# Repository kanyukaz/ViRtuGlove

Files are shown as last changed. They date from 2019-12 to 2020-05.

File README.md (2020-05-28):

# ViRtuGlove 0.9
This goal of this project to create a haptic feedback glove that can be used with consumer virtual reality (VR) systems. Presently, the project employs the following core features:
* 3 D0F rotational acceleration tracking for each digit (and for the hand to serve as a reference)
* anti-contractile haptic feedback for each digit
* assessment of contractile resistance against the haptic feedback system

Currently, the project does not have full integration with a VR system, but does include functioning (albeit in need of minor debugging) systems for exchanging sensor and actuator signals with a host computer. Please see the /src folder for my Arduino sketch and a companion script for Unity3D. These scripts provide a foundation for integration with a variety of VR interfaces.



[pic1]: https://github.com/kanyukaz/ViRtuGlove/blob/master/img/prototype.jpg "VR Glove"

Repository Contents
============

* **/documentation** - documentation for this project and its predecessor
* **/hardware** - models for the unused part prototypes and circuit schematics to summarize the electronic boards that I have built
* **/img** - images for the readme, including a product photo and circuit schematic diagrams.
* **/libraries** - the libraries for presently used versions of Adafruit sensor libraries (keeps the code functional in case current versions are not available in the future, and future versions are not backwards compatible).
* **/scr** - the Arduino sketch, the companion script for Unity3D, and code used for debugging

* **LICENSE** - The license file.
* **README.md** - The file you're reading now! :-D

Requirements and Materials
============
Dependencies:
* Adafruit Unified Sensor library V1.0.3
* Adafruit L3GD20 U Sensor library V1.01

Both of these are available through Arduino IDE's built-in library manager, but backups are included in the /libraries section

Bill of Materials:
* 1 x Arduino MEGA
* 1 x VR-capable computer
* 5 x Adafruit L3GD20H gyroscope breakouts
* 1 x Adafruit 9D0F sensor breakouts
* 5 x TOWERPRO SG-5010 servomotors
* 5 x Adafruit INA169 current sensor breakouts
* 1 x TCA9548A I2C multiplexer
* 1 x 180 cm derailleur cable
* 1 x tight-fitting elastic glove 
* L x Velcro
* L x cushion foam
* L x hot glue 
* L x flexible perfboard
* L x ribbon cable
* L x jump-wire
* L x header pins, male and female

L - liberal amounts of; exact amount depends on the assembler's skill in assembling the project and individual design variations. 

Bill of Tools:
* wire stripper
* wire cutter
* hot glue gun
* soldering iron 

Build Instructions
==================
Below, I have described the way I have build the project. Variant access to resources, time, and alternative materials leaves flexibility in many of the methods used. Please note that most of the build procedure is an excerpt from the term project write-up paper which is included in the /documentation directory. 

**Overall structure** 

The glove's construction consists of three main units: the microcontroller unit, which is mounted on the user's upper arm; the servomotor unit, which is mounted on the user's lower arm; and the hand unit, which is mounted on the user's hand. The microcontroller unit, held to the user's arm with an elastic armband, includes the Arduino MEGA microcontroller with a custom shield that facilitates a one-cable link to the electronic components of the other two units. The servomotor unit, held to the user's arm by a short sleeve includes the servomotor control board which powers and controls the servomotors and assesses the current drawn by each. Additionally, the servomotor unit has attachment points for each servomotor. Lastly, the hand unit, held to the user's hand by a tight-fitting work glove includes a gyroscope management board, a haptic feedback application bracket, and a haptic feedback harness. Below, I will describe each of these units, the connectivity between them, and the servomotor subunits in more detail.

I built the electronic boards described on the base of consumable flexible perfboard material. I used standard male and female header pins to build cable connectors. All electronic connections other than the cable connectors were reinforced with solder. All structural connections were reinforced with hot glue.

**The servomotor subunits** 

The haptic feedback mechanism employed by the prototype uses servomotors to pull the user's digits via metal cables opposite to the digits' contractile direction. The system is powered by a set of five TOWERPRO SG-5010 servomotors, one for each digit. To harness the power of the servomotors, a cable was attached to the far end of each servo's arm, and channelled through one of the built-in mounting holes. A 180 degree rotation of the servo arm results in a 4 cm range of motion for the cable. To allow flexibility in mounting the servos, the force is conveyed through a 30 cm derailleur cable. To summarize, a servo subunit consists of a servomotor, a derailleur cable with one end loose and the other end attached using hot glue to the mounting hole that serves as a cable channel, and a cable that is attached to the arm and passes through the derailleur cable. In the assembled prototype, the loose end of the derailleur cable is glued to the eyelets of the haptic feedback application bracket on the hand unit, and the servos are flexibly mounted at the servomotor unit using Velcro. 

**Inter-unit connectivity and power**

The microcontroller unit serves as the bridge between the transducers, the power source, and the host. The Arduino MEGA is connected to the host computer using a USB type A/B cable, and it is connected to the power adapter through the barrel-shaped power jack.

The electronic components of the three units are connected using two propitiatory ribbon cables. The servomotor subunit is connected to the microcontroller subunit using a 15-pin male-male ribbon cable, which I will refer to as cable A for the rest of the paper. Cable A has 5 PWM lanes (used for servo control), 5 analogue lanes (used for ammeter readings), SCL and SDA lanes for I2C communication (for gyros), a single free digital lane for future expansion, a Vin lane, and a ground lane. The connector for cable A is L-shaped to avoid the possibility of accidentally plugging it in the wrong orientation. The microcontroller subunit and servomotor subunits have corresponding female connectors for cable A. The custom shield for the Arduino MEGA serves as the microcontroller's adapter for cable A. The electronic components of the hand unit are connected to those on the servomotor unit (and by extension, through cable A to the microcontroller unit) via a 5-pin male-male ribbon cable which I will refer to as cable B. Cable B has SCL and SDA lanes for I2C communication, a single free digital lane for future expansion, a Vin lane, and a ground lane. Like cable A, it is L-shaped and has corresponding female connectors on the units that it links. The servomotor unit serves in part as a pass-through for the microcontroller's connection to the gyros. I formed the connectors using ribbon cable, male and female headers (where appropriate). Then I reinforced and insulated the male connectors using hot glue. It should also be noted that the Vin and ground connections make up system-wide power and ground rails. 

**Hand unit**

The hand unit is held to the user's hand through an elastic work glove. I chose a tight-fitting glove for the project to ensure close adherence to a wide range of hand sizes. The tips of each fingers are reinforced with a thimble fashioned out of wire and hot glue. Cables attached to the thimbles are threaded through the glove along the outer edge of each digit so they could be attached to the servomotor subunits' cables at the haptic feedback bracket. This local cable system makes up the haptic feedback application harness. Velcro mounting points for gyroscopes are placed on middle phalanges of each finger, and the proximal phalanx of the thumb. Positioning the gyroscopes on these joints best allows for extrapolation of finger conformation with a single sensor per digit. The Velcro haptic feedback bracket attachment point spans the back of the glove. The extensive use of Velcro throughout the arm  hand unit allows easy serviceability and inter-user adjustment. 

The haptic feedback bracket is a metal structure with a flat base parallel to the user's metacarpals and eyelets that serve as attachment points for the loose ends servomotor subunits' derailleur cables. The end of the bracket closest to the phalanges has five functional eyelets through which the distal ends of the servo subunits' derailleur cables are threaded. Here,  adjustable links between the servo-attached cables and harness-attached cables is made by twisting together the ends of each. Thus, the servos are mechanically linked to the tips of the user's fingers, completing the haptic feedback system. 
	
Early design of the project relied on the possibility of 3D printing structural pieces for the hand unit. These include gyro mounts with lobes when one can drill pass-throughs for haptic feedback harness cable for each digit. Additionally, I planned to 3D print a lightweight, plastic haptic feedback bracket with a shape moulded by the user's hand. When printing initial prototypes for the gyro mounts revealed the limited availability of 3D printers, the design was changed to what can be seen in the final product, and no further part prototypes were made.
	
I used hot glue to mount the gyroscope communication board atop the haptic feedback bracket. The schematic diagram for the board can be found below. The board consists of five Adafruit L3GD20 3DOF gyroscope breakout boards permanently connected to the communication board through 4-line ribbon cables. Each such cable has SCL and SDA lanes for I2C communication, a Vin lane, and a ground lane. Additionally, an Adafruit 9DOF sensor breakout board which includes a L3GD20 gyroscope has been mounted directly on the gyroscope communication board. It can serve as a reference point for the other gyroscopes.  Its additional accelerometers have not been implemented in this project, but remain an open for future development. The electronic components implemented on the gyroscope communication board use I2C for communicating with the microcontroller. Because all L3GD20H gyroscopes used share the same I2C address, they are managed with an Adafruit TCA9548A I2C multiplexer digital breakout board. Each sensor's I2C pins are linked to respective corresponding pins on the multiplexer. All of the breakout boards use the shared Vin and ground rails. As previously mentioned, this unit connects to the other units through cable B.

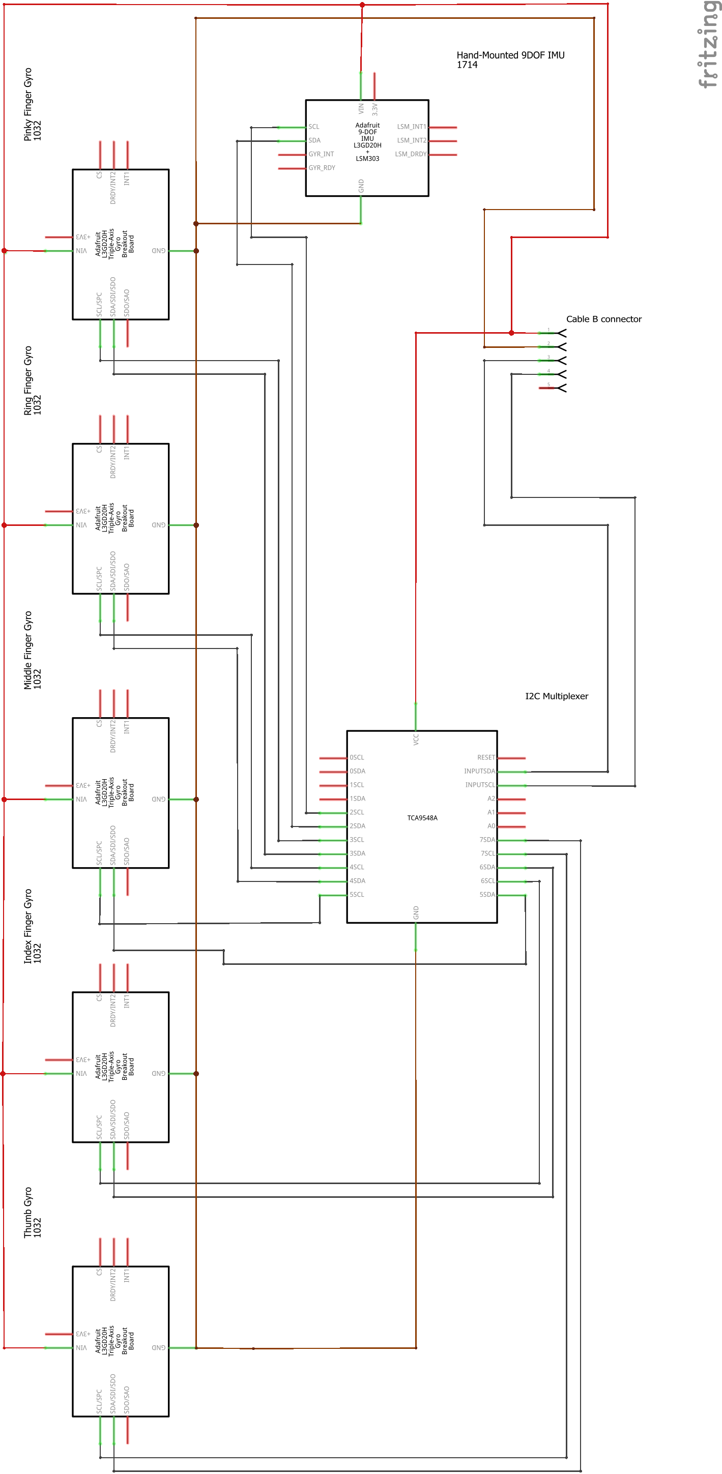
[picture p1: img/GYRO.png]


[pic2]: https://github.com/kanyukaz/ViRtuGlove/blob/master/img/GYRO.png "Hand unit board circuit schematic"

**Servomotor unit**

To facilitate mounting on the lower arm, a short sleeve fashioned out of another elastic work glove is used as the structural base for the servomotor unit. I mounted the servomotor control board on a piece of cushion foam with a base that is shaped to follow the curvature of the user's arm. This strategy enhances structural stability when mounting the large board to a user's body. Throughout the circumference of the sleeve, I placed Velcro attachment points for the servomotors. When the unit is assembled, the servomotors are connected to the appropriate headers on the servomotor control board.
	
The servomotor control board integrates two key functions of the prototype - management of haptic feedback and assessment of resistive contractile strength. The schematic diagram for the board can be found below. The board has five three-pin male headers common among shields made for servomotors. Each header has ground pin, a Vin pin, and a PWM communication pin. The five INA169 current sensors serve as a proxy between the servo headers' Vin pins and the global Vin power rail. This allows them to monitor the current drawn by the servomotors. The current sensors have Vin, ground, and analog signal pins, as well as the pins between which the current is measured and travels to the servos headers. The servo header PWM pins and the current sensors' analogue pins make a direct and exclusive connection with the the corresponding pins on the microcontroller through the cable A link. The board additionally serves as a pass-through to the hand unit, to which it is connected via cable B.

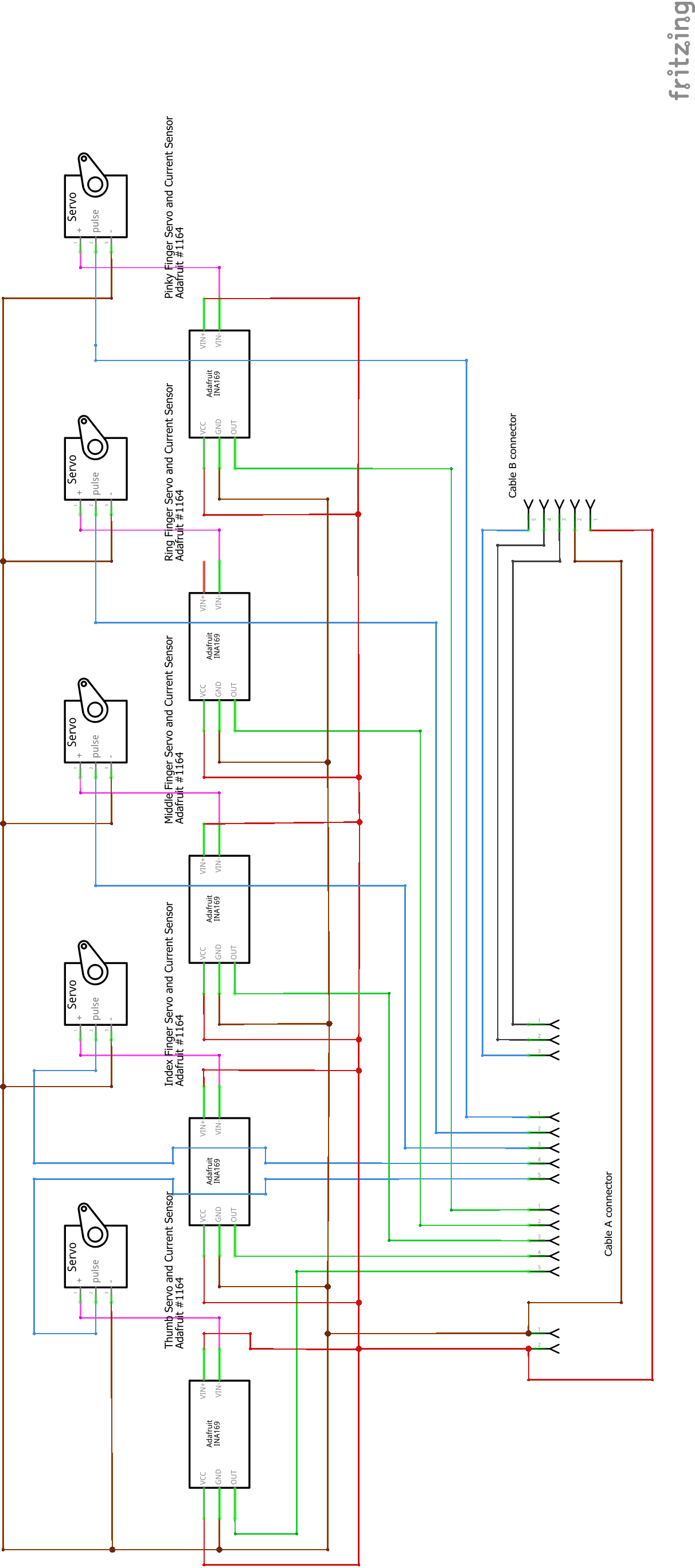
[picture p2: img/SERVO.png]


[pic3]: https://github.com/kanyukaz/ViRtuGlove/blob/master/img/SERVO.png "Servomotor unit board circuit schematic"

**Microcontroller unit**

The Arduino MEGA microcontroller board is mounted to the user's upper arm with an adjustable elastic armband. The outward surface of the custom-made shield consists solely of the female connector for cable A. The schematic diagram for the shield can be found below. On the flip-side, the female connector's pins are connected as follows: five analogue lines used for current sensors are connected to analogue pins 0-4; five PWM lines used for servo control and the expansion digital pin are connected to digital pins 2-6 and 7 respectively; and the Vin rail and ground rail lines are connected to Vin and ground pins respectively. As explained before, this unit is used for handling communication to the host via USB, managing the supply of power, and mediating the transducers. I have included further information on the firmware used by the microcontroller in the sections below. 
  
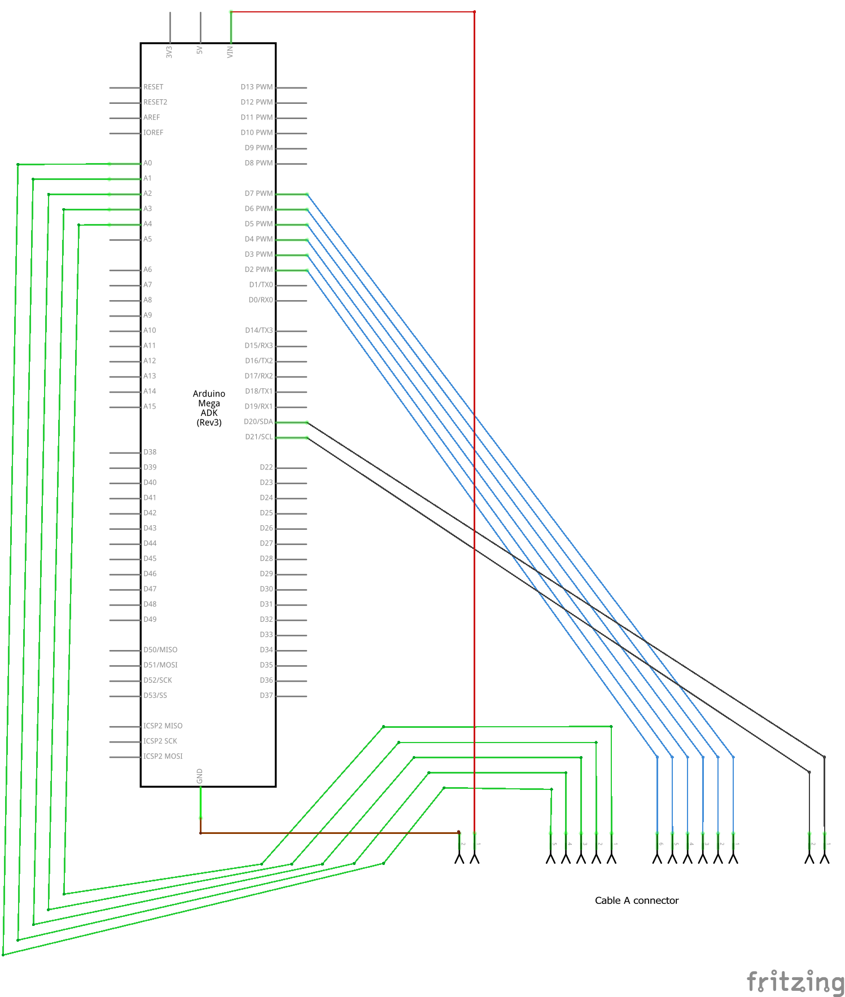
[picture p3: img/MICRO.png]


[pic4]: https://github.com/kanyukaz/ViRtuGlove/blob/master/img/MICRO.png "Microcontroller unit shield circuit schematic"

Usage
=====
**Assembly**

Thread your right hand and arm through the microcontroller unit's armband, followed by the servomotor unit's sleeve, and the hand unit's glove. Adjust the armband and the sleeve for a snug, yet comfortable fit. Then, with the digits fully contracted and the haptic feedback cables in a fully extended position, adjust the position of the haptic feedback bracket until the cables are lightly tensioned. When disconnected from any power source, the servo arms can be manually adjusted to make this possible. If necessary, adjust the lengths of the cables at the link between the servo subunit's and haptic feedback harness cables. After this, reposition the gyroscopes so they are in the middle of the middle phalanges of each finger, and the proximal phalanx of the thumb. Finally, ensure that cables A and B are firmly connected and the microcontroller is connected to the host and the power source. Depending on the setup, USB and mains extension cords may be desirable. To implement the glove with a VR system, use a Velcro strap to tether a VR controller anywhere on the lower arm where it will be visible to the tracking systems.  The project becomes active and starts communicating with the host once the serial port to the host is open.

**Unity3D interface script**

The Unity3D companion script offers a rudimentary graphic user interface, allowing the user to view the numeric signals the host receives from the glove and control the servomotors via sliders. Variables that handle each of these are publicly available to other scripts, and the script already takes references to joints of an OpenVR hand model, making it ripe for further development of a VR interface. 

Team
=====
The build team consists of: 
* Zakhar Kanyuka -- I designed and built the project

A special thanks is to the University of Regina Department of Computer Science for providing me with the resources for the project and helping me extensively with troubleshooting. 

Credits
=======
* The i2c scanner found in /src/debugging was adapted from riyas-org; the original can be found at: https://gist.github.com/riyas-org/a394774cd605789964530612c3fb3dbc

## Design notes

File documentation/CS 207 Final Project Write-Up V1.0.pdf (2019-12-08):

# Virtual Reality Glove Project Write-Up

### Zakhar Kanyuka

### December 7, 2019

## Contents

1 Introduction | 4
2 Inspirations | 5
3 Design and build process | 6
4 Software overview | 11
5 Manual | 13
6 Build process, current state, and future directions | 14
Appendix A | 18
Appendix B | 19

Appendix C | 20
Appendix D | 21

## 1 Introduction

Some of the limitations of modern consumer-grade virtual reality (VR) systems include

restricted spatial representation of the user’s body and only rudimentary haptic feedback.

Successful systems from Oculus and HTC offer infra-red camera-based spatial tracking of the

user’s hands and head. Additionally, they extrapolate the user’s hand conformation from the

signals from the triggers and touch-sensitive elements found on the controllers. As a result,

the user’s freedom of manual movement that is represented in the virtual environment is

confined by the shape and features of the controller. Furthermore, both major companies’

controllers offer no haptic feedback besides a vibration motor and the shape of the controller.

While many developers have been successful in making engaging VR experiences that help

the users forget about hardware’s limitations, a more comprehensive manual interface than

the existing controllers can be an upcoming step in refining VR products.

In this project, I set out to build a prototype of such a manual interface in the form

of a glove. For each digit, I implemented respective orientation tracking, haptic feedback,

and contractile force assessment mechanisms. To track the each digit’s three-dimensional

orientation relative to the palm of the hand, I used gyroscopes mounted on each digit and

one on the back of the hand. The one-dimensional haptic feedback mechanism restricts digit

contraction with the help of servomotors mounted on the user’s lower arm. The contractile

force exerted by the user against the haptic feedback mechanism is measured using ammeters

which assess the current drawn by each servomotor to maintain position. The management

of the transducers and the communication with the VR host device are mediated by an

Arduino MEGA microcontroller board mounted on the user’s upper arm. Full VR integration

of the glove relies on spatial tracking facilitated by attachment of an existing VR system’s

controller. A companion script for Unity3D provides a framework for future integration in

VR experiences. Other goals of the project included maximizing hardware reliability and

inter-user fit.

## 2 Inspirations

A glove is hardly a new format for a controller in the world of VR and similar applications.

Glove-based peripheral prototypes such as the Sayre glove developed at the University of

Illinois have existed since the 1970s. The first VR-centric glove was released by VPL Research

in 1987, a company at the centre of early VR development. More famously, in 1989, Nintendo

released the Power Glove as a separately sold companion for their contemporary NES system.

However, most of these projects saw little success due to prohibitive cost and limitations of

the available technology. Furthermore, most focused solely on representation of the user’s

hand in virtual space with no haptic feedback system. More recently, small-scale companies

such as CyberGlove, HaptX, and VRfree have put out impressive prototypes of gloves that

offer feature sets akin to my project. However, these typically have heavy, unwieldy, or

complex exoskeletons through which they apply haptic feedback. Most such projects are

little-reviewed and have yet to reach the marketplace. For a more comprehensive review

of the above and other glove-based peripherals, please see my past work, The Ultimate

Controller [3].

Despite commercial failures of similar peripherals in the past, a haptic VR glove continues

to be an appealing interface for enhancing entertainment, training, and telepresence applica-

tions of VR technology. This inspired me to build the first version of a VR glove prototype

in early 2019. Most notably, the glove used a set of flex sensors to assess contractile position

of each digit, a set of small hand-mounted servomotors to exert haptic anti-contractile feed-

back, and conductive stretch-sensing cord to sense the user’s resistance to haptic feedback.

While successful as a proof-of-concept, the glove suffered from poor structural integrity, only

a single degree of freedom per digit in assessing contractile position, and excessive signal noise from stretch-sensing cord. The development of this project is described in detail in

The Ultimate Controller [3]. The prototype described in this paper is meant to be a progres-

sion of the aforementioned project, addressing its flaws. Similar to the previous project, the

present prototype differentiates itself from other offerings with a combination of the lack of

an exoskeleton (an advantage as exoskeletons tend to make gloves heavy and unwieldy or un-

necessarily complicated), 3 degree-of-freedom digit tracking, and a current-based assessment

system for user-applied force.

## 3 Design and build process

### 3.1 Overall structure

The glove’s construction consists of three main units: the microcontroller unit, which is

mounted on the user’s upper arm; the servomotor unit, which is mounted on the user’s lower

arm; and the hand unit, which is mounted on the user’s hand. The microcontroller unit, held

to the user’s arm with an elastic armband, includes the Arduino MEGA microcontroller with

a custom shield that facilitates a one-cable link to the electronic components of the other two

units. The servomotor unit, held to the user’s arm by a short sleeve includes the servomotor

control board which powers and controls the servomotors and assesses the current drawn by

each. Additionally, the servomotor unit has attachment points for each servomotor. Lastly,

the hand unit, held to the user’s hand by a tight-fitting work glove includes a gyroscope

management board, a haptic feedback application bracket, and a haptic feedback harness.

The following subsections will describe each of these units, the connectivity between them,

and the servomotor subunits in more detail.

I built the electronic boards described on the base of consumable flexible perfboard

material. I used standard male and female header pins to build cable connectors. All electronic connections other than the cable connectors were reinforced with solder. All

structural connections were reinforced with hot glue.

### 3.2 The servomotor subunits

The haptic feedback mechanism employed by the prototype uses servomotors to pull the

user’s digits via metal cables opposite to the digits’ contractile direction. The system is

powered by a set of five TOWERPRO SG-5010 servomotors, one for each digit. To harness

the power of the servomotors, a cable was attached to the far end of each servo’s arm, and

channelled through one of the built-in mounting holes. A 180° rotation of the servo arm

results in a 4 cm range of motion for the cable. To allow flexibility in mounting the servos,

the force is conveyed through a 30 cm derailleur cable. To summarize, a servo subunit

consists of a servomotor, a derailleur cable with one end loose and the other end attached

using hot glue to the mounting hole that serves as a cable channel, and a cable that is

attached to the arm and passes through the derailleur cable. In the assembled prototype,

the loose end of the derailleur cable is glued to the eyelets of the haptic feedback application

bracket on the hand unit, and the servos are flexibly mounted at the servomotor unit using

Velcro.

### 3.3 Inter-unit connectivity and power

The microcontroller unit serves as the bridge between the transducers, the power source,

and the host. The Arduino MEGA is connected to the host computer using a USB type

A/B cable, and it is connected to the power adapter through the barrel-shaped power jack.

The electronic components of the three units are connected using two propitiatory ribbon

cables. The servomotor subunit is connected to the microcontroller subunit using a 15-pin

male-male ribbon cable, which I will refer to as cable A for the rest of the paper. Cable A has 5 PWM lanes (used for servo control), 5 analogue lanes (used for ammeter readings),

SCL and SDA lanes for I2C communication (for gyros), a single free digital lane for future

expansion, a Vin lane, and a ground lane. The connector for cable A is L-shaped to avoid

the possibility of accidentally plugging it in the wrong orientation. The microcontroller

subunit and servomotor subunits have corresponding female connectors for cable A. The

custom shield for the Arduino MEGA serves as the microcontroller’s adapter for cable A.

The electronic components of the hand unit are connected to those on the servomotor unit

(and by extension, through cable A to the microcontroller unit) via a 5-pin male-male ribbon

cable which I will refer to as cable B. Cable B has SCL and SDA lanes for I2C communication,

a single free digital lane for future expansion, a Vin lane, and a ground lane. Like cable A,

it is L-shaped and has corresponding female connectors on the units that it links. The

servomotor unit serves in part as a pass-through for the microcontroller’s connection to

the gyros. I formed the connectors using ribbon cable, male and female headers (where

appropriate). Then I reinforced and insulated the male connectors using hot glue. It should

also be noted that the Vin and ground connections make up system-wide power and ground

rails.

### 3.4 Hand unit

The hand unit is held to the user’s hand through an elastic work glove. I chose a tight-

fitting glove for the project to ensure close adherence to a wide range of hand sizes. The tips of

each fingers are reinforced with a thimble fashioned out of wire and hot glue. Cables attached

to the thimbles are threaded through the glove along the outer edge of each digit so they

could be attached to the servomotor subunits’ cables at the haptic feedback bracket. This

local cable system makes up the haptic feedback application harness. Velcro mounting points

for gyroscopes are placed on middle phalanges of each finger, and the proximal phalanx of the thumb. Positioning the gyroscopes on these joints best allows for extrapolation of finger

conformation with a single sensor per digit. The Velcro haptic feedback bracket attachment

point spans the back of the glove. The extensive use of Velcro throughout the arm hand unit

allows easy serviceability and inter-user adjustment.

The haptic feedback bracket is a metal structure with a flat base parallel to the user’s

metacarpals and eyelets that serve as attachment points for the loose ends servomotor sub-

units’ derailleur cables. The end of the bracket closest to the phalanges has five functional

eyelets through which the distal ends of the servo subunits’ derailleur cables are threaded.

Here, adjustable links between the servo-attached cables and harness-attached cables is made

by twisting together the ends of each. Thus, the servos are mechanically linked to the tips

of the user’s fingers, completing the haptic feedback system.

Early design of the project relied on the possibility of 3D printing structural pieces for

the hand unit. These include gyro mounts with lobes when one can drill pass-throughs for

haptic feedback harness cable for each digit. The model for these can be seen in Appendix

D. Additionally, I planned to 3D print a lightweight, plastic haptic feedback bracket with

a shape moulded by the user’s hand. When printing initial prototypes for the gyro mounts

revealed the limited availability of 3D printers, the design was changed to what can be seen

in the final product, and no further part prototypes were made.

I used hot glue to mount the gyroscope communication board atop the haptic feedback

bracket. The schematic diagram for the board can be found in Appendix A. The board

consists of five Adafruit L3GD20 3DOF gyroscope breakout boards permanently connected

to the communication board through 4-line ribbon cables. Each such cable has SCL and SDA

lanes for I2C communication, a Vin lane, and a ground lane. Additionally, an Adafruit 9DOF

sensor breakout board which includes a L3GD20 gyroscope has been mounted directly on the

gyroscope communication board. It can serve as a reference point for the other gyroscopes.

Its additional accelerometers have not been implemented in this project, but remain an open for future development. The electronic components implemented on the gyroscope

communication board use I2C for communicating with the microcontroller. Because all

L3GD20H gyroscopes used share the same I2C address, they are managed with an Adafruit

TCA9548A I2C multiplexer digital breakout board. Each sensor’s I2C pins are linked to

respective corresponding pins on the multiplexer. All of the breakout boards use the shared

Vin and ground rails. As previously mentioned, this unit connects to the other units through

cable B.

### 3.5 Servomotor unit

To facilitate mounting on the lower arm, a short sleeve fashioned out of another elastic

work glove is used as the structural base for the servomotor unit. I mounted the servomotor

control board on a piece of cushion foam with a base that is shaped to follow the curvature

of the user’s arm. This strategy enhances structural stability when mounting the large board

to a user’s body. Throughout the circumference of the sleeve, I placed Velcro attachment

points for the servomotors. When the unit is assembled, the servomotors are connected to

the appropriate headers on the servomotor control board.

The servomotor control board integrates two key functions of the prototype - management

of haptic feedback and assessment of resistive contractile strength. The schematic diagram

for the board can be found in Appendix B. The board has five three-pin male headers

common among shields made for servomotors. Each header has ground pin, a Vin pin, and

a PWM communication pin. The five INA169 current sensors serve as a proxy between the

servo headers’ Vin pins and the global Vin power rail. This allows them to monitor the

current drawn by the servomotors. The current sensors have Vin, ground, and analog signal

pins, as well as the pins between which the current is measured and travels to the servos

headers. The servo header PWM pins and the current sensors’ analogue pins make a direct and exclusive connection with the the corresponding pins on the microcontroller through the

cable A link. The board additionally serves as a pass-through to the hand unit, to which it

is connected via cable B.

### 3.6 Microcontroller unit

The Arduino MEGA microcontroller board is mounted to the user’s upper arm with an

adjustable elastic armband. The outward surface of the custom-made shield consists solely

of the female connector for cable A. The schematic diagram for the shield can be found

in Appendix C. On the flip-side, the female connector’s pins are connected as follows: five

analogue lines used for current sensors are connected to analogue pins 0-4; five PWM lines

used for servo control and the expansion digital pin are connected to digital pins 2-6 and 7

respectively; and the Vin rail and ground rail lines are connected to Vin and ground pins

respectively. As explained before, this unit is used for handling communication to the host

via USB, managing the supply of power, and mediating the transducers. I have included

further information on the firmware used by the microcontroller in the sections below.

## 4 Software overview

### 4.1 The Arduino sketch

The Arduino MEGA microcontroller is programmed with two main functions in mind

- conveying the states of the sensors to the USB connected host, and operating the haptic

feedback system based on the host’s instructions. Every loop, the microcontroller collects

the singular signals from each current sensor, and three signals from each gyroscope. Then,

it concatenates integer values that represent these signals, into a comma-separated string

bounded by characters ’s’ in the beginning and ’e’ in the end. The characters serve as a form of parity so the receiver can ensure that the string is intended to be an input. The string is

then passed to the host over the serial port.The sketch is also designed to receive instructions

in a similar format, but with five signals to dictate the positions of the servomotors and a

remaining signal to control the unimplemented digital pin on the hand unit. The sketch

parses the signals in the string to integers and applies them to the respective digital output

pins.

The sketch switches between the I2C multiplexer’s channels using a function provided

by online by Adafruit [1]. I used an additional sketch adapted from Github user riyas-org’s

i2cscanner to reveal all of the I2C device addresses available on the I2C bus [2]. This was

an asset when debugging I2C communication. Additionally, when, after implementing the

I2C multiplexer, gyroscopes intermittently failed to initialize, stalling the sketch and causing

serial communication with the host to time out. I found that inserting the core portion of

the I2C scanner code as a for loop had an activating effect on the sketch. This solution

remedied the stalling problems.

### 4.2 Unity3D interface script

To ease integration with VR systems, I wrote a script that enables Unity3D to com-

municate with the glove over the serial port, parse its signals to local public integers and

concatenate output signals in the appropriate format. The script is designed to be placed

under a hand model GameObject and serve as a starting point for future VR integration.

In its present state, it takes but does references to but does not manipulate the Transform

parameters of joint objects of an OpenVR hand model.

## 5 Manual

### 5.1 Assembly

Thread your right hand and arm through the microcontroller unit’s armband, followed by

the servomotor unit’s sleeve, and the hand unit’s glove. Adjust the armband and the sleeve

for a snug, yet comfortable fit. Then, with the digits fully contracted and the haptic feedback

cables in a fully extended position, adjust the position of the haptic feedback bracket until

the cables are lightly tensioned. When disconnected from any power source, the servo arms

can be manually adjusted to make this possible. If necessary, adjust the lengths of the

cables at the link between the servo subunit’s and haptic feedback harness cables. After

this, reposition the gyroscopes so they are in the middle of the middle phalanges of each

finger, and the proximal phalanx of the thumb. Finally, ensure that cables A and B are

firmly connected and the microcontroller is connected to the host and the power source.

Depending on the setup, USB and mains extension cords may be desirable. To implement

the glove with a VR system, use a Velcro strap to tether a VR controller anywhere on the

lower arm where it will be visible to the tracking systems.

### 5.2 Unity3D interface script

The Unity3D companion script offers a rudimentary graphic user interface, allowing the

user to view the numeric signals the host receives from the glove and control the servomotors

via sliders. Variables that handle each of these are publicly available to other scripts, and

the script already takes references to joints of an OpenVR hand model, making it ripe for

further development of a VR interface.

## 6 Build process, current state, and future directions

### 6.1 Build process

Much of the assembly went as expected. Soldering of the electronic components, for

instance, although extensive and time-consuming, was highly successful and required minimal

trouble-shooting. Mostly, each of the breakout boards and servomotors functioned as per

their design. Furthermore, after the purchase of a hot glue gun, assembly of structural

components became relatively quick.

Unfortunately, there were also numerous setbacks. The USB controller on first Arduino

MEGA that I received for the project became corrupted, necessitating a re-flash at a later

date. Diagnosing this problem and replacing the microcontroller board took up some valu-

able work time. At the same time I was also resolving some misconceptions surrounding I2C

communication and the use of Adafruit’s sensor libraries. Troubleshooting the two problems

had compounding effects. Additionally, the original plans of the project relied heavily on

3D printing. However, working, available 3D printers and personnel who are qualified to use

them proved unexpectedly difficult to find. By the time I had decided to seek alternative

solutions, the delay had taken its toll on the project’s schedule. At the final stages of the

project, I also found out that I needed an I2C multiplexer to handle the six gyroscopes with

identical I2C addresses; I ordered the part promptly, but because this occurred before a

weekend, it took several days. When the part arrived and was implemented, inexplicable

issues arose in initializing the connected gyroscopes. Lastly, throughout the development

phase of the project, several situations arose in my other four classes that took up unexpect-

edly large amounts of time to resolve. Because of the additive effects of these setbacks, I was

left with little time to maintain any milestones (besides the second for a somewhat functional

Arduino sketch), troubleshoot the project, and implement a usable VR application.

### 6.2 Current state

Despite the delays, however, I was able to build a piece of functioning, interactive hard-

ware which serves as a springboard for further development. Each of the implemented

transducers have proven to work in the development environment. The glove successfully

sends, receives, and parses signals over the serial port. Additionally, testing the prototype

with a user who has smaller but more massive hands and arms than I do shows that the glove

maintains inter-user fit. Thus, many of the project’s core goals have been at least partially

fulfilled.

On the flip-side, the glove’s physical construction proved to be unreliable. Particularly,

the links between the servo arms and the haptic feedback cables in the servomotor subunits

tend to snap because they use metal solder as a structural component. I learned that this

was a poor design choice soon after as I attended a soldering demonstration lecture where

this technique was discussed in a negative light. Nonetheless, there was little time left to

fix the mistake, and the solder joints proved a point of failure some during the final project

demonstrations.

The Unity3D companion script is another aspect of the project that needs refinement.

While some of its previous iterations worked smoothly without a VR setup, further refine-

ments to implement the script with a VR system caused the serial communication with the

glove to stall, unable to read the glove’s output.

Lastly, because of the time constraints, and last minute setbacks on the board where it is

to be connected, I did not implement a planned vibration motor. In the hardware, therefore,

its infrastructure gives rise to a single digital PWM pin available for future expansion on the

hand unit.

### 6.3 Future directions and conclusion

I would like to continue the development of this project in the future. The first steps will

include development of a more reliable system for linking haptic feedback cables to servo

arms, refining the firmware and companion Unity3D scripts, and implementing the vibration

motor. Then, I would like to 3D print gyroscope attachment hardware and a lighter haptic

feedback application bracket, facilitating a more natural and predictible fit for for the hand

unit. Finally, I would like to develop a VR experience that takes advantage of the VR glove.

After these key goals are complete, I would like to benchmark the glove against my previous

prototype and any other gloves that I can get my hands in.

While I did not reach all of my desired goals in the project, given the time constrains the

prototype is highly impressive. It offers three degree-of-freedom tracking, a robust anti-

contractile haptic feedback mechanism, and a functioning means to measure contractile

force for each digit. This feature-set alone makes the prototype noteworthy and worthy

of refinement in the future.

## References

(1) Adafruit TCA9548A 1-to-8 I2C Multiplexer Breakout Wiring and Text https : / /

learn.adafruit.com/adafruit-tca9548a-1-to-8-i2c-multiplexer-breakout/

wiring-and-test (https://learn.adafruit.com/adafruit-tca9548a-1-to-8-i2c-multiplexer-breakout/wiring-and-test) (accessed 12/02/2019).

(2) i2c scanner by riyas-org https://gist.github.com/riyas-org/a394774cd605789964530612c3fb3dbc

(accessed 12/02/2019).

(3) Kanyuka, Z. The Ultimate Controller, 2019.

## Appendix A

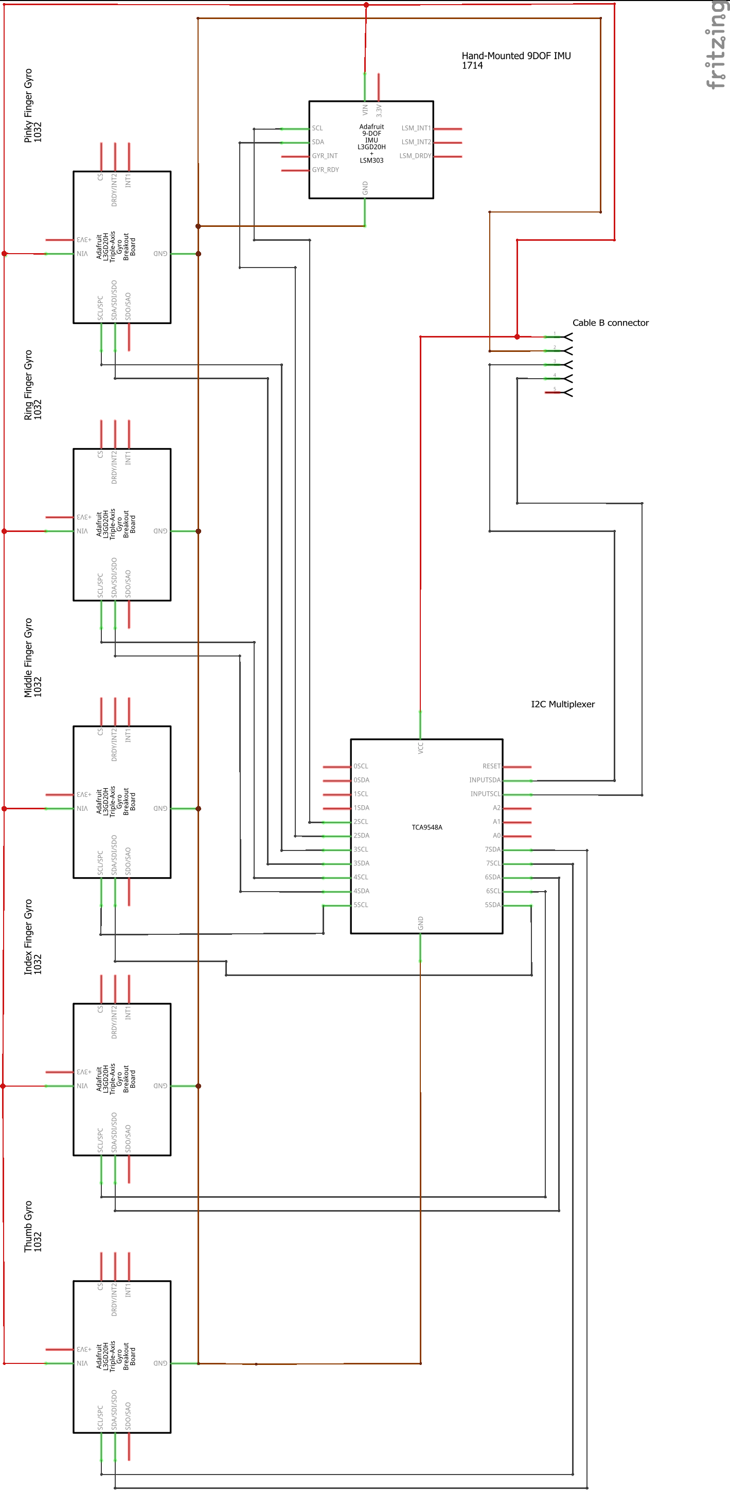
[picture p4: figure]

The design schematic for the gyroscope management board. The circuit was implemented as designed.

## Appendix B

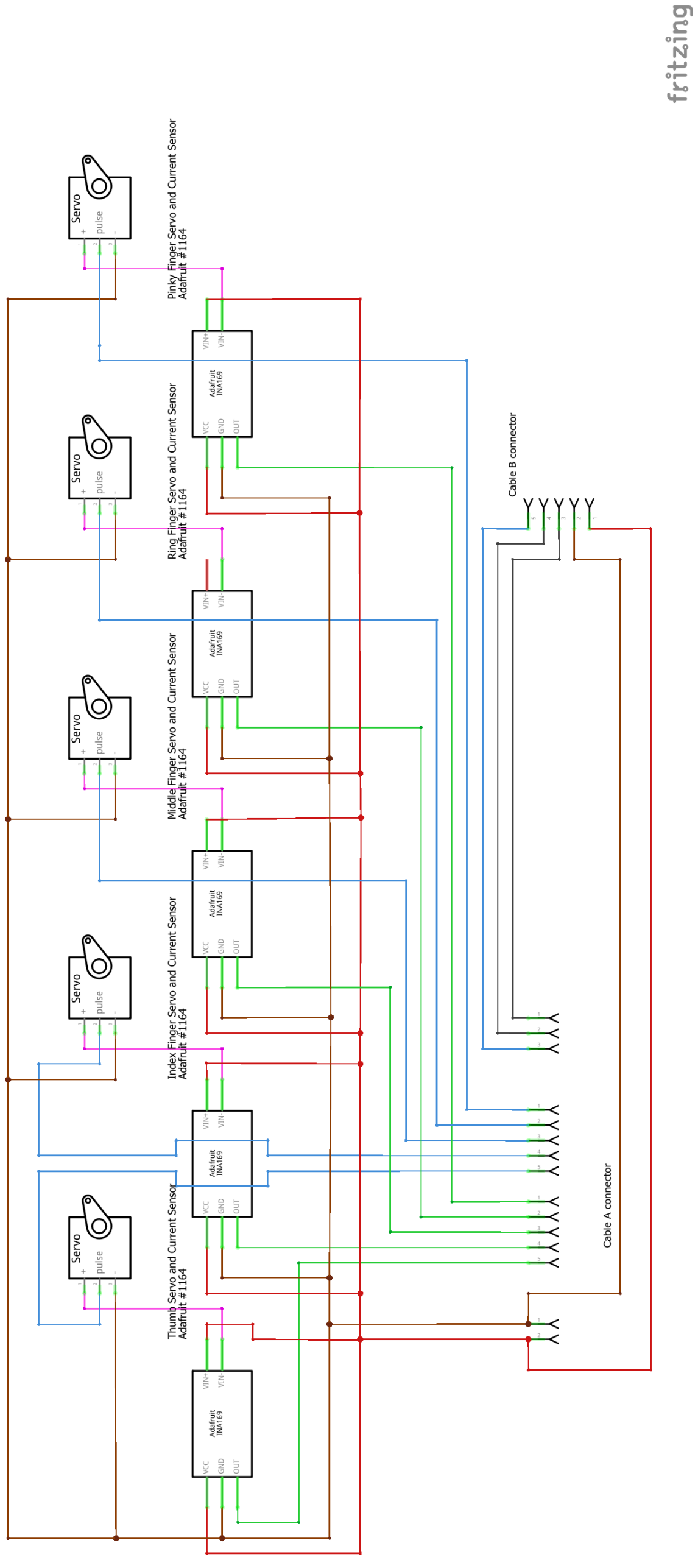
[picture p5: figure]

The design schematic for the servomotor control board. The circuit was implemented as designed.

## Appendix C

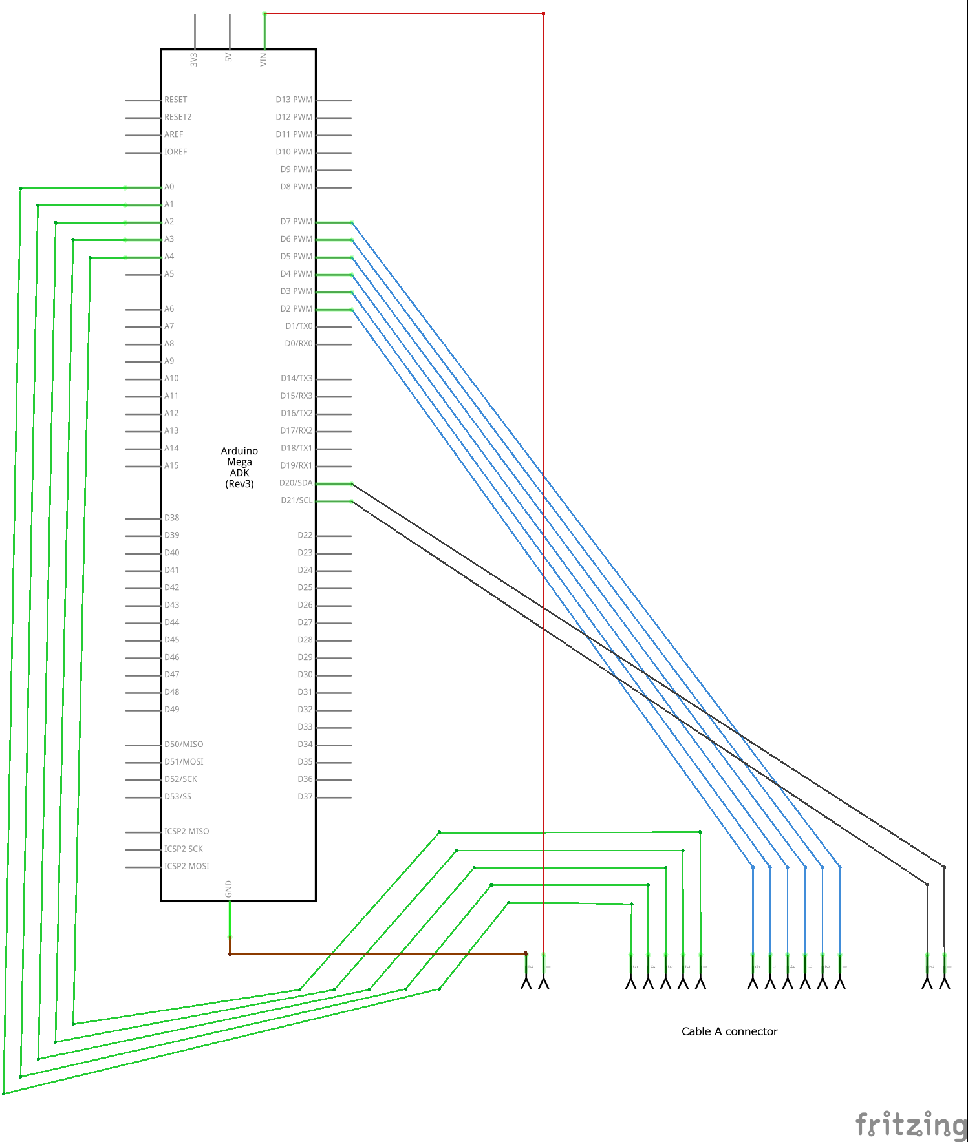
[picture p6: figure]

The design schematic for the shield that allows the Arduino MEGA microcontroller to communicate with the rest of the prototype via cable A. The circuit was implemented as designed.

## Appendix D

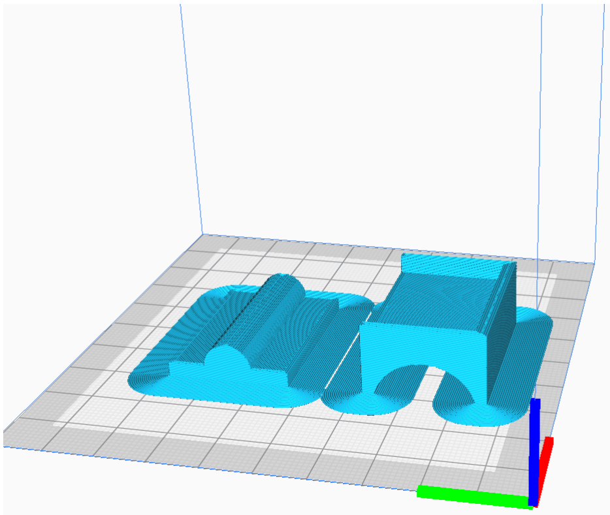
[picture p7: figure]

The model for the unused digital gyroscope mounting unit pre-sliced in Ultimaker Cura. While the part prototype was acceptable, no more than one copy could be printed before the project deadline, so the model was not used.

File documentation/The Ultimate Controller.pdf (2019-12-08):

Kanyuka | 1

# The Ultimate Controller

Zakhar Kanyuka | CS 390 AP

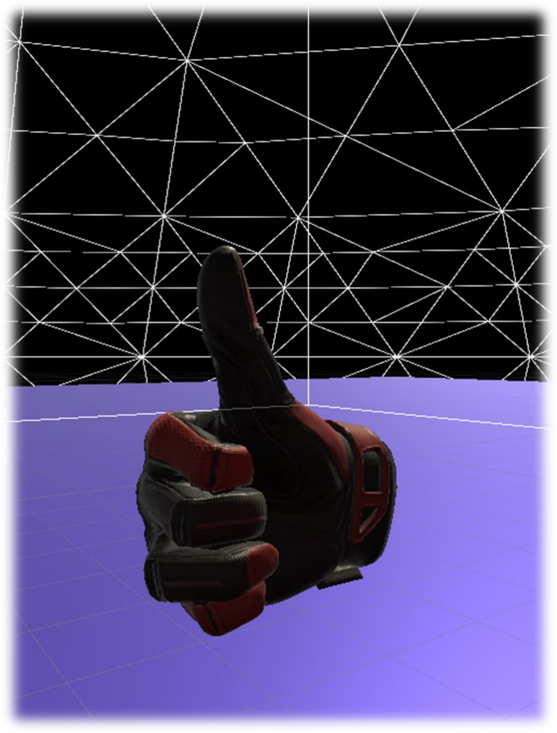
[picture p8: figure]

## Introduction and Justification

### The Human Hand

Few anatomical features give humans as many ways of interacting with their surroundings as

their hands. Thanks to the dexterity facilitated by the combination of complex structure, and intricate

neurological control over the hand, we have been able to undertake a wide selection of tasks that led us

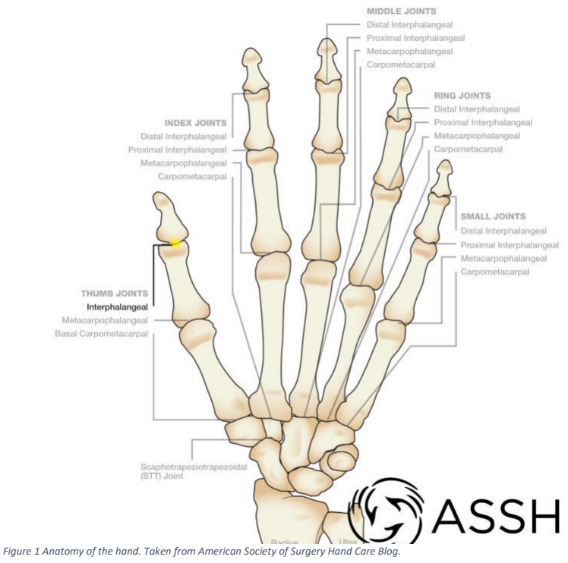
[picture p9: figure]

to the rich, diverse thriving societies we have today. Throughout the evolutionary journey, hands have

been key to making and using tools and weapons, growing and harvesting food, creating art, playing

Figure 1 Anatomy of the hand. Taken from American Society of Surgery Hand Care Blog.

games, and sharing ideas. As the staple of the human experience, therefore, it should be inevitable that

hands get a worthy representation in virtual reality (VR).

### The Problem with Common Controllers

Ivan Sutherland’s “The Ultimate Display,” a document viewed by some as the manifesto for the

development of VR in years to come, describes the ideal interface as multisensory (Sutherland, 1965).

Among other senses, he encourages the engagement of haptics through input mechanisms that convey

to the user the feeling of force; although he proposes the use of body parts other than hands and arms

to interact with the virtual world, he acknowledges the value of manual interaction due to the hands’

superior dexterity (Sutherland, 1965). With the spread of personal computing, most systems take

advantage of the users’ manual dexterity for their primary sources of input such as keyboards, mouses,

pen tablets, and gamepads. Most of these devices also provide rudimentary haptic feedback either

through tactile buttons whose engagement the user can easily distinguish, or though vibration motors.

While they fall short of taking advantage of numerous degrees of freedom and immense sensory

capacity offered by the hands, they are sufficient for navigating the simple, abstract interfaces we see

on most two-dimensional displays; this is in part thanks to the agreement among the users and

developers of the given systems on standardized control schemes such as pressing ‘W,’ ‘A,’ ‘S,’ and ‘D’

on a keyboard to move an avatar in a computer game or turning a dial to adjust the shutter speed on a

camera. Modern head-based VR systems can transport the user to a world where he or she can naturally

interact with three-dimensional objects, no longer limited to the abstract two-dimensional interfaces of

pancake systems. Although it can improve the user-friendliness of a system, reaching an agreement on

control schemes to be used across VR applications would restrict the possibilities of a virtual universe

where nearly anything is possible; using control schemes established for use in a pancake system would

hinder the user’s ability to naturally manipulate the virtual world. To achieve optimal interaction with a

VR experience designed to mechanistically mimic the real world, the peripherals must therefore allow for natural interaction mechanics. An interface which snugly fits the user’s hand such as a glove or an

exoskeleton is essential to achieving natural interaction with the virtual world.

### Early Glove-Shaped Peripherals

Sayre Glove, developed by University of Illinois’ researchers in 1977, is credited as the first of

glove-based peripherals to come. However, the idea saw little commercial success until the release of

the DataGlove by VPL Research in 1987. Taking advantage of the optical flex sensor patent given to them

two years prior, and magnetical motion tracking offered by Polhemus, the DataGlove was ground-

breaking for the time period. Owing in part to VPL Research founder Jaron Lanier, who coined the term

“virtual reality,” the DataGlove is regarded as one of the first peripherals made for VR. While the $8800

asking price kept it of the public’s hands, the DataGlove found its way into research and industrial

applications, most notably NASA’s VIEW program aimed at using VR technology for training and

telepresence (Pollack, 1989; Rosson, 2014). With the aim of putting a glove-shaped peripheral on the

hands of the everyman gamer, Mattel released the inexpensive, $75 Power Glove controller for the

Nintendo NES in 1989 (Struman & Zeltzer, 1994). Due to the limited, 2 bits per finger tracking made

possible by contemporary technology at the price point and the lack of games available for the system,

the Power Glove was a commercial failure (Struman & Zeltzer, 1994). Furthermore, the Power Glove was

left out of the field of head-based VR as it was discontinued in 1990, 5 years before Nintendo released

the Virtual Boy head-mounted display system. Glove-shaped peripherals soon intersected with the

gaming world again when W Industries (precursor to Virtuality) released the Space Glove,

technologically intermediate between the DataGlove and the Power glove (Struman & Zeltzer, 1994).

The Space Glove did not become widespread among consumers as the W Industries’ VR systems were

marketed and priced primarily for arcade use.

### Current State of VR Peripherals

Like Nintendo’s Virtual Boy and other low-cost VR systems from the 1990s, many modern head-

based VR systems use control schemes carried over from pancake systems. Google’s Daydream VR and

Samsung’s Gear VR used simple remotes with rotational tracking, whereas early Oculus Rift headsets

shipped with Xbox One gamepads. To make better use of the spatial tracking of room-scale VR, Oculus’s

Rift and HTC’s Vive systems received controllers that shared the precise positional and rotational

tracking technologies of their respective headsets. Combined with intuitive button layouts, this gave the

user a less restricted interaction with the virtual world than ever, granting the ability to approach, pick

up, throw and point objects in any direction. However, even when using the innovative controllers, the

users remain largely tied to the joysticks, buttons, and triggers carried over from gamepads of the past.

This comes back to the incompatibility of pancake system control schemes for VR applications. For

example, although the user can use the controller’s motion tracking to place his or her hand over an

interactable element in the virtual world such as a drawer handle, grabbing at it remains puzzling –

should one press a specific button on the controller, squeeze the hand grip, or merely place a finger on

the trigger? Furthermore, upon solving the puzzle and performing the correct action, the user must

learn of his or her success through a readjustment of the hand position or at best a light buzz from the

controller’s vibration motor or rely on visual cues. This is a far cry from the precise haptic feedback

delivered to the hand by every concrete object one touches, which often gives the ability to perform

tasks blindly. The perfect controller would therefore take away the layer of abstraction posed by

today’s controllers between a VR user and the virtual world.

### Overview of Recent Glove-Shaped Peripheral Prototypes

Numerous companies, many new on the market, continue to put forward prototypes for glove-

shaped VR peripherals. Since the release of the original CyberGlove, a glove capable of tracking the

conformation of the user’s hand, in 1990, CyberGlove Systems have continued until recently to evolve

the product, and developed a fleet of systems based on the contemporary CyberGlove iterations.

Notable products are the CyberTouch, which delivers tactile feedback through a set of six vibro-tactile

actuators, and the CyberGrasp, which delivers force feedback by manipulating an exoskeleton on the

user’s hand. Unfortunately, the exoskeleton construction of the CyberGrasp is criticized for being heavy

at 400 grams (Burdea, 2000). Their development has become stagnant and none of the marketing

material features the use of modern consumer VR systems. Conversely, newer glove-shaped peripherals

have a greater focus on integration with the HTC Vive and the Oculus Rift. A promising Kickstarter

project VRgluv yielded a prototype glove capable of hand tracking and force feedback through an

exoskeleton. However, even after reaching its funding goal, the company is not transparent about the

details of the glove’s technology and there are few, if any, units in the hands of the public. Furthermore,

the expected weight is similar to that of the CyberGrasp, which was formerly found problematic. The

HaptX Glove prototype uses set of IMUs to track digit positions and deliver force feedback through a

pneumatic exoskeleton which the manufacturer claims to be lightweight. Most impressive, however, is

the HaptX Glove’s further use of the pneumatic system to deliver tactile feedback through a set of 130

pneumatic actuators spread throughout the glove. A simpler offering is the VRfree prototype by

Sensoryx, which relies on IMUs for hand tracking but offers no haptic feedback. While the few publicly

available reviews of modern VR-oriented glove-shaped peripherals are largely favourable, the

practicality, viability of construction, physical characteristics, price, and in some cases underlying

technology will remain unknown until after the products are readily available to mainstream developers

and the public.

## Design Overview

The prototype implements a conductive ink-based flex sensor, a conductive rubber stretch

sensing cord, and a servo motor for each digit. The design decisions for each of the sensors and the

servo motors are addressed in the upcoming sections of the paper. Using an elastic work glove as the

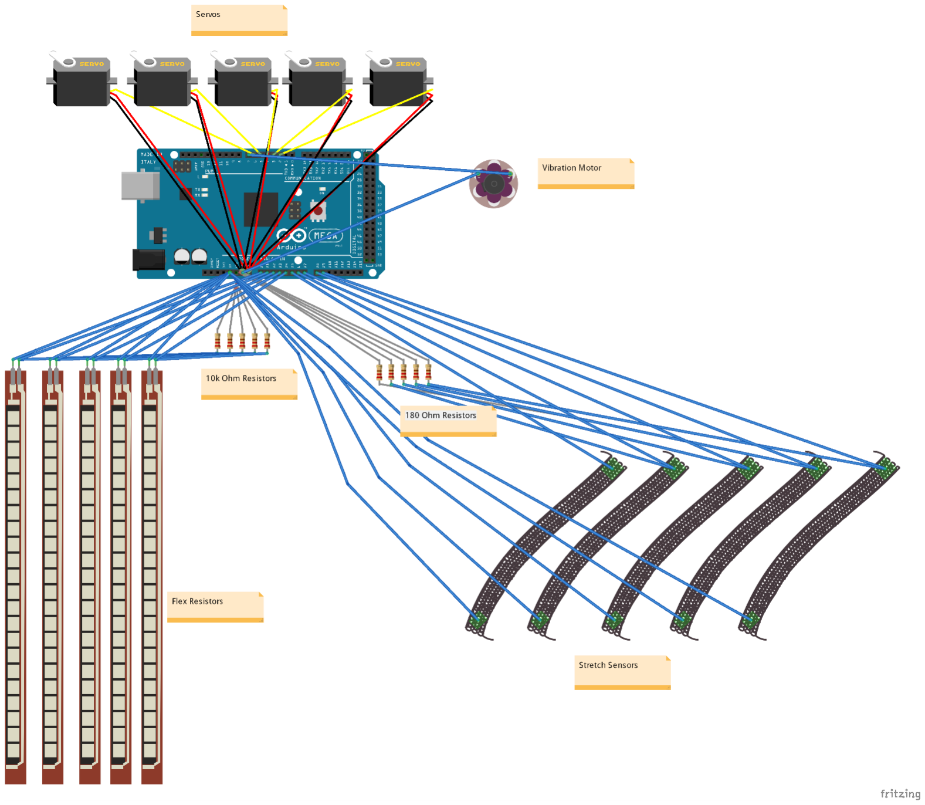
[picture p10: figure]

basis for the prototype, ensures that the prototype is easy to place and adjust on the user’s hand.

Although a system that requires attachment of its individual components to the user’s hand may

achieve better accuracy, it would also be cumbersome to attach it to and detach it from the user. I

attached the base of each flex sensor in front of the proximal phalanges on the outer edges of each

digit. To ensure free, yet unitary movement of the flex sensors with the digits, each is surrounded with a

cloth channel attached securely to the glove. The servo motors are attached and stabilized on the glove

Figure 2 Overview of prototype's circuit.

with a mounting plate designed in Google SketchUp Make 2017, and 3D printed using ABS plastic. The

mounting plate consists of two pieces that are flexibly connected with wire, and sewn to the back of the

glove. An earlier version of the servo mounting plate consisted of a single 100 mm wide piece, and did

not adhere well to the curvature of the top of the user’s hand, which resulted in the variation of

distance between the fingers and the servos during operation. The size and orientation of the servo

motors does not allow for the possibility to make the mount significantly narrower. Instead, the

mounting plate was widened to a collective width of 120 mm to accommodate a more robust mounting

architecture, and split into two pieces, yielding a degree of freedom that allows flexible adhesion to the

hand. By making contact with more of points on the hand, the latest iteration of the servo mount

achieves greater stability than its predecessor. An alternative solution would be mounting the servo

motors elsewhere on the arm and transmitting the applied force using cables. However, this design

would offer little benefit; thanks in part to the use of ABS plastic for the basis of the mount and a lack of

a complex exoskeleton, the glove (excluding the Arduino board) weights 160 grams, less than half the

weight of similar products which weigh as much as 400 grams, which makes weight reduction a low

priority; any system used to transfer the force exerted by the relocated servo motors to the fingers

would incur a loss of force and introduce undesirable elasticity in the force delivery system. Servo

motors are secured using zip ties. Velcro straps that thread through loops formed by zip ties are used to

secure the attachment of the servo motor mounting plate and the VR system’s controller to the user’s

hand. The horns of the servo motors are connected to the tips of respective digits through an assembly

consisting of the stretch sensors and wire. The portions of the wire connected to the servo horn doubles

as the power lead for the stretch sensor, reducing the need for additional cables, while a resistor serves

as a mounting point of a stretch sensor at the tip of the digit. Threading one end of the resistor through

the stretch sensor and plugging each end of the resistor into a removable connector for communication

with the Arduino board constructs the desired circuit, fulfils a structural role for the stretch sensor, and allows easy replacement of the fragile conductive stretch sensing rubber cord. Loops of thread and

plastic channels mounted at the base of flex sensors serve to center each stretch sensor’s path of

movement, which is important to ensure consistency of signal between contractions of the digits. A

vibration motor can be placed in the glove on the inner side of the user’s wrist, where it does not

interfere with the functionality of any other parts of the glove.

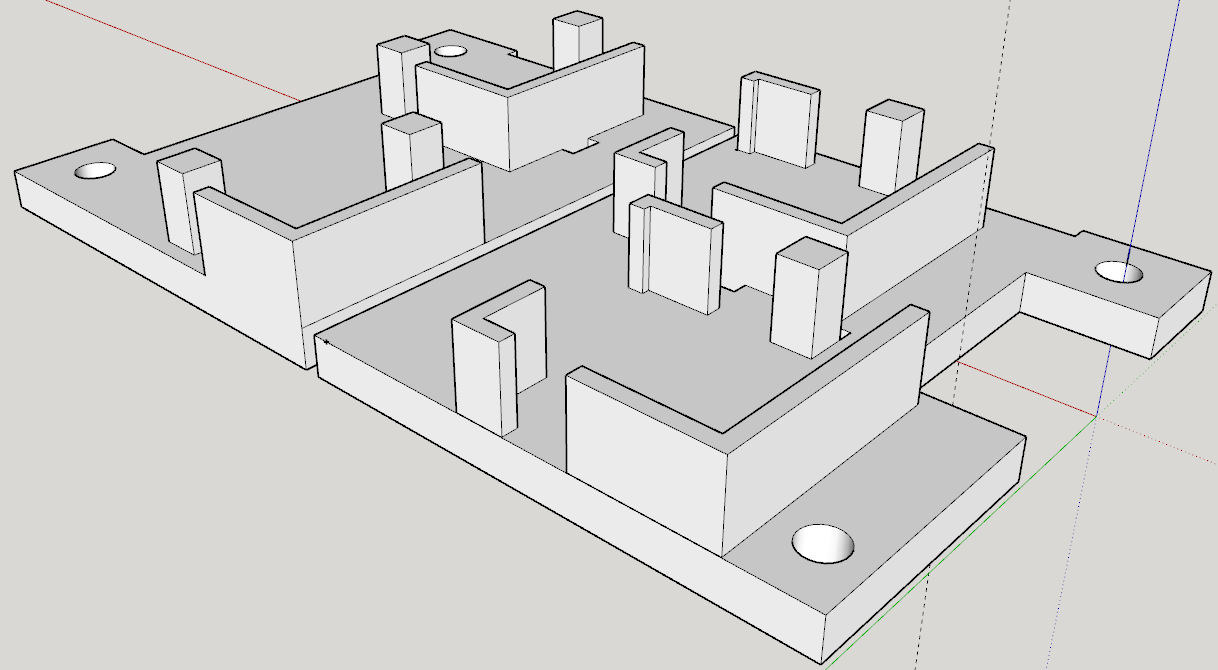
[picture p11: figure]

Figure 3 Model of servo motor mounting plate.

Data gathered from sensors and the operation of motors is managed by an Arduino Mega

microcontroller board, mounted with a Velcro strap to the user’s arm to avoid placing additional weight

and bulk on the user’s hand. For easy serviceability, the sensors are connected with double-sided female

header cables to male header pins soldered to a project shield. To ensure sufficient power delivery for

the servo motors, a supplemental power supply is necessary. The Arduino is connected to the host

device through USB.

## Digit Tracking

Conveying the position and curvature of each finger to the host device has been a core feature

of glove-shaped peripherals since the early days of the Sayre Glove. It is the foundation of a glove-

shaped peripheral – without awareness of his or her hand’s conformation, delivery of haptic feedback,

or detection of force application would be futile for most foreseeable use cases. Therefore, it serves as a

starting point for the prototype.

### Justification

Manual interactions such as picking up a pistol for combat, turning a screwdriver to

repair a vehicle, or twisting the hand into a gesture to signal teammates are central to many VR

experiences. While interacting with the surroundings, the user can examine the avatar’s hand

model, often exploring the steps that have been taken to make it more believable. Additionally,

each interaction calls for unique motions and hand positions. Because of the differences in their

size and shape, holding a revolver would feel vastly different from holding a smartphone. The

level of abstraction of the environment posed by common controllers puts a choice before the

developers between making each interaction as unique in VR as it is in the real world or using

an agreed-upon control scheme. While the first approach can make for a more engaging

experience, it necessitates the user learning a separate sequence of buttons to press and

triggers to squeeze for every interaction. Conversely, applying a generalized control strategy to

all interactions reduces the user’s learning curve at the cost of removing him or her from the

diverse geometries of the virtual objects he or she touches. An accurate representation of the

hands removes the burden of this choice as it gives the developers the opportunity to take

advantage of realistic hand conformations for interactions without requiring a steep learning

curve for the user as the motions called for by the experience are learned in day-to-day life.

Realistic representation of the behaviour of one’s digits in the virtual world would therefore

greatly increase the believability and intuitiveness of an experience.

### My Implementation

To asses digit flexion, my glove uses a set of five conductive ink based flex sensors, one for each

finger. To reduce the physical stress near the connective leads and ease connection to Arduino with

female-to-female connector cables, the sensors are linked to male header pins supported by a piece of

flexible breadboard. To unite the movement of the flex sensor with the finger, the sensor is loosely

placed within a cloth channel sown to the glove’s fingers where it can freely move along the digit while

being forced to follow its flexion.

Each assembly is mounted on the outside of the glove at the base of the digit’s proximal

phalange. The flex sensors are positioned over the proximal interphalangeal joints of the fingers, giving

the glove 1 DOF tracking on each finger. The proximal interphalangeal joint was chosen for its nearly

135° range of movement and involvement in most finger movement. While the metacarpophalangeal

joint offers a similar range of motion, common hand positions have a lesser effect on its angle. The distal

interphalangeal joint has around 30° range of movement and its position is closely linked to that of the

proximal interphalangeal joint. The interphalangeal joint is chosen on the thumb for a similar reason.

Once the sensors are connected to Arduino’s analog input pins, the data can be read and stored

in integer variables. The beginning of the Arduino’s sketch code globally declares each digit an integer

variable for storing the value read from the flex sensor, and a constant integer to hold the value of the

analog pin on the Arduino associated with each flex sensor. For example, such declarations for the index

finger flex sensor are as follows:

int flxInd;

const unsigned int FLEX_2_PIN = 2;

Within void Loop(), the Arduino calls the function readFlex(), which reads the potential of the

analog pins to which the flex sensors are connected and stores the resulting value in the appropriate

variable.

void readFlex(){

flxThu = analogRead(FLEX_0_PIN);

flxInd = analogRead(FLEX_1_PIN);

…

}

After this, the collected data in the integer variables is collected into a string packet which is sent over

the serial connection to the host device. The digit positions of the hand model can be calculated from

the flex sensor data in the 3D engine.

### Overview of Other Implementations

Digit tracking has been a fundamental goal of glove-shaped peripherals since the early days.

Over time, manufacturers have taken a myriad of different approaches to fulfil this goal. VPL’s

DataGlove uses optical flex sensors to capture the angles of different joints. Thanks to the simplicity of

implementation, different types of flex sensors continue to be abundant in similar peripherals, used

similarly in the Nintendo Power Glove, and the CyberGlove family of devices. Prototypes from Exos use

hall effect sensors, although the company’s design documentation proposes the use of potentiometers

to track the conformation of an exoskeleton that encompasses the user’s fingers as another option.

Most recently, prototypes from HaptX and Sensoryx use IMUs to track the behaviour of digits.

### Discussion

Achieving Comprehensive Tracking
A fundamental limitation of my design for finger tracking is the lack of tracking of the

metacarpophalangeal joint positions. While it is true that the proximal interphalangeal joints are heavily

involved in most activities undertaken by hands, the user can control the orientation of the metacarpophalangeal joint independently from the rest of the hand with respect to two degrees of

freedom, making it necessary for building an accurate hand conformation model. Tracking a

metacarpophalangeal joint poses a level of difficulty above that of a proximal interphalangeal joint

because besides flexion it is also involved in lateral extension of the digits. The challenge extends to the

trapezometacarpal joint found at the base of the thumb which similarly offers two degrees of freedom.

One approach to achieving a more comprehensive hand tracking model is using more flex

sensors to capture all the intricacies of the hand’s conformation. Because each flex sensor can only

capture a single degree of freedom, accounting for each independently movable element of the hand

can require upwards of 20 sensors. For example, iterations of VPL Research’s DataGlove use data from

16 flex sensors, the latest CyberGlove is offered with up to 22 flex sensors. Alternatively, using finger-

mounted IMUs greatly simplifies the construction of the glove. Sensoryx VRFree glove uses 11 IMUs, one

on each of the interphalangeal joints, and one on each joint of the thumb. It would, however, be

sufficient to use 8 6 degree of freedom IMUs, one placed on each of the fingers’ middle phalanges, one

on each of the thumb’s phalanges, as both can be operated independently, one on the palm, and one on

the user’s wrist. The positional and rotational data from each IMU can then be used to infer the states of

any points that are not tracked directly but are coupled to parts of the hand whose location and rotation

are known.

Sensor Choice and Signal Quality
Even when the flex sensors are left undisturbed, the analog signal read by the Arduino is prone

to fluctuation. Nisar et al. propose that the signal can be stabilized by adding a small-value, non-polar

capacitor in parallel with the conductive ink based flex sensors to reduce the ripples from the power

source (2014). Furthermore, they emphasize the importance of reliable attachment of the sensor to the

glove and thermal insulation (Nisar et al., 2014). A Kalman filtering algorithm can be used to reduce

signal noise in software. Better results may also be found by using other types of sensors. The VPL

Research DataGlove makes use of fiber optic flex sensors. Meanwhile, Exos, who engineered a series of

glove-shaped peripherals with exoskeletons, propose a series of approaches that include monitoring

positions of joints of the glove’s exoskeleton with potentiometers, placing hall effect sensors on the

exoskeleton, and inferring the conformation of the digit from the position of the motor used for haptic

feedback. When IMUs are used for finger tracking, repeatability, stability, and drift are other factors that

are important to consider (“IMU Errors and Their Effects”). Besides structural considerations, choosing

the best sensor finger tracking necessitates further comparison of signal consistency, noise, and fidelity.

## Haptic Feedback

While hand tracking is a valuable first step, and is often sufficient for entertainment

applications, haptic feedback widens the applicability of a glove-shaped peripheral. VR applications

across many industries stand to gain from an accurate representation of virtual objects. Furthermore,

user force detection, discussed in the next section of the paper, is reliant on an opposing force being

exerted by a haptic feedback system. As such, this is the next piece of the glove’s design that must be

implemented.

### Justification

In accordance with Newton’s third law, which states that for every action there is an equal and

opposite reaction, everything we touch responds with a similar force. Thanks to this property of the

physical world, people rely heavily on the haptic senses. Without looking, one can know whether he or

she has successfully picked up an apple, pressed a key on a remote, or crushed an empty can. Except for

the unchanging feel of its buttons and triggers, and rudimentary vibration feedback, today’s common VR

controllers do little to convey the rich haptic experience of physical interactions. Sutherland proposes a

kinesthetic display consisting of levers that variably resist forces to give the user force feedback (1965).

Project GROPE demonstrated the viability of Sutherland’s concept by comparing subjects’ performance

while using interfaces with and without force feedback as they participated in a series of abstract educational tasks such as finding optimal docking of a molecule in a protein’s reactive site (Brooks et al.,

1990). The multidecade project revealed that force feedback gives the participant an edge (Brooks et al.,

1990). Because haptic feedback is a major component of people’s perception of the world,

immersiveness and educational potential of VR experiences would stand to gain from a haptic feedback

system that dynamically and believably conveys forces, forms, and tactile feel of virtual world.

### My Implementation

Form Depiction
To convey the form of a virtual object, I use a set of servo motors mounted to the back of the

hand, one for each digit. The motors’ horns are coupled to the user’s fingertips through electrical cable

and a piece of conductive rubber stretch sensing cord. To ensure that the connective assembly travels

along the outer edge of each digit consistently, it is threaded through plastic tube that is mounted at the

base of the flex sensor and extends past the proximal interphalangeal joint and stabilized near the tip of

the digit with a loop of thread. To depict the approximate shape of a virtual object, the servo motors

retract the connective cables, individually limiting the inward flexion of each digit.

I chose servo motors to depict haptic feedback because they are easy to position precisely, can

be lightweight, and require minimal external equipment to operate. Regular constant rotation motors

are not easy to position precisely. Stepper motors are bulkier and offer no advantage over a servo motor

in the given application. A recurring approach in the glove-shaped peripheral industry is the use of

pneumatics. While the ability to easily apply force over a wide area and move the actuator away from

the hand makes this option tempting, because of the thermal, barometric, and volumetric instability of

air, a pneumatic system can be cumbersome to design in a way that delivers a consistent haptic

response. Furthermore, a pneumatic system typically requires an external unit and a complex control

structure to manage inflation of individual air pockets, which can make such a system unwieldy.

The position of each servo motor can be dictated by the Arduino’s pulse width modulation

(PWM) capable digital pins. Arduino IDE’s built-in libraries abstract the PWM interface used to

communicate with a servo motor to calling a function with the parameter of the desired horn angle in

degrees. First, it is necessary to include the appropriate library with the statement:

#include <Servo.h>

Then the Arduino’s sketch code globally declares the pin associated with each servo, the Servo object,

and an integer variable to hold the desired servo angle for each digit. Such a declaration for the middle

finger is as follows:

const unsigned int SERVO_2_PIN = 4;

Servo serMid;

int sersMid;

Within the Arduino’s setup() function, each servo object is linked to a unique PWM pin. For instance,

the middle finger servo motor is initiated by calling:

serMid.attach(SERVO_2_PIN);

Upon initiation, the servo motor becomes immobilized and maintains the position dictated by the PWM

signal. Because of this, the servos’ built-in potentiometers cannot be used to infer finger position.

In each iteration of the Arduino’s loop() function, each servo’s desired position is read from the

data packet received from the host device and stored it the respective integer variable, a topic covered

in the section of this paper on serial communication. Then, each servo is directed to the desired

position. For example, the middle finger servo is directed to the angle in the variable sersMid by calling:

serMid.write(sersMid);

This function alters the PWM signal delivered to the servo’s data connection to signal the desired angle.

Vibration Feedback
The vibration motors found in common VR controllers give the user a useful degree of haptic

feedback, indicating that he or she has successfully fired a pistol or picked up an object. To continue to

take advantage of this mechanic, I implemented a single vibration motor in the glove-shaped peripheral.

The vibration motor can be turned on and off by applying a high or low voltage to the digital pin it is

connected to on the Arduino. First, the pin responsible for operating the vibration motor and a Boolean

variable that controls the state of the vibration motor are globally declared:

const unsigned int VIBRATE_PIN = 7;

bool vibrate;

Then, within the Arduino’s start() function, the digital pin’s mode must be set:

pinMode(VIBRATE_PIN, OUTPUT);

When the Boolean variable responsible for manipulating vibration is enabled through the serial port, a

high signal is applied to the pin that powers the vibration motor. Else, a low signal is applied.

if(vibrate == true)

digitalWrite(VIBRATE_PIN, HIGH);

else

digitalWrite(VIBRATE_PIN, LOW);

### Overview of Other Implementations

Over time, two primary approaches to providing the user force feedback emerged –

exoskeletons and pneumatics. Exos’ prototypes, CyberGlove’s CyberGrasp, and the more modern VRgluv

exert force to the user’s hand through an exoskeleton system which provides robust and direct control

over respective joints. Other systems, notably the Teletact II and a novel rehabilitation system designed

by Connely et al. (2010) inflate pneumatic pockets to achieve a similar effect. HaptX draws from both

design paradigms in a design that involves a minimal, pneumatically actuated exoskeleton.

Less common is the implementation of tactile feedback. In similar designs, CyberGlove’s

CyberTouch and the TactGlove use vibro-tactile actuators and piezo sounders, respectively, to deliver

rudimentary tactile feedback on the user’s fingers. Although little is yet known about HapteX’s tactile

feedback system which takes advantage of pneumatic actuators, the prototype appears to provide the

most comprehensive tactile feedback system available.

### Discussion

Limits of Shape Depiction
Upon first inspection, my approach to portraying the shape of a virtual object is dwarfed by past

endeavours. My system only offers a single degree of freedom and only limits inward flexion for each

digit. Meanwhile Exos’ SAFIRE single-finger prototype can manipulate the operator’s finger with respect

to two degrees of freedom, and CyberGlove’s CyberGrasp offers three degrees of freedom for each digit

(Eberman, 1993). However, each of these systems relies on an exoskeleton to deliver the actuators’

forces, which adds weight, bulk, and potential points of failure to the system. Teletact II takes a different

approach to reflecting shapes and forces by placing 30 pneumatic pockets around the hand (Stone,

2000). This method, however, requires a fast, complex pneumatic system to inflate and deflate the air

pockets at a rate that would make the experience believable. A pneumatic system adds complication,

expense, and bulk to the product. My system, therefore, is uniquely simple.

Flex in Connective Assembly
The conductive rubber stretch sensing cord within the connective assemblies of the prototype

Easily stretches with little force, which detracts from the rigidity of the depicted shape. Lack of a rigid

attachment of the plastic tubes through which the connective assemblies are routed further contributes

to the undesired effect. The first factor can be mitigated by using thicker or more rigid stretch sensing

cord for force detection. If such a conductive material cannot be obtained, the stretchable part of the

connective assembly a piece of more rigid non-conductive material can also be attached alongside. Both factors could further be minimized by routing the connective assemblies through a channel formed with

solid plastic rings and thimbles for each finger.

Vibration and Tactile Feedback
The haptic experience would further be enhanced with realistic engagement of tactile senses.

Haptx’s glove delivers an impressive and comprehensive depiction of tactile feedback using 130

pneumatic chambers distributed throughout the glove which can be inflated to stimulate the sense of

touch. An easier-to-implement method, carried out by CyberGlove’s CyberTouch and the TactGlove, is

placing vibration motors or piezo sounders in the palm and finger assemblies to increase the resolution

possible with vibration feedback.

## Force Detection

To maximize the benefits of a glove-shaped VR system and the believability of the experience, a

dedicated force detection system is highly beneficial. Reliant on hand tracking and a force feedback

system, it must be implemented as a final step.

### Justification

Forces lie at the core of the haptic experience. We must exert forces with our hands to pick up,

crush, and press the objects around us; merely placing our hands around objects is usually insufficient to

achieve these actions. A haptic display, as described in the previous section, conveys the forces

sustained by the avatar’s hand without directly capturing the forces the user exerts with his or her hand

in response. This limits the representation of objects that deform under pressure (Budea, 2000). If one

applies sufficient force to an empty tin can, it collapses. Likewise, a button that is being pressed first

meets the user with a degree of resistance before the switch caves to the pressure. To accurately

represent the composition of a can or the tactile feedback of a button in a virtual space, the user’s

interface must reflect the forces applied by each digit.

### My Implementation

To asses the forces applied by each digit, I use a 4 cm piece of conductive rubber stretch sensing

cord within the junction between servo horns and the tip of the user’s finger. Each end of the

conductive rubber cords is supported by the cables that, besides having a structural role, link it to the

Arduino. I chose to use stretch sensors rather than pressure sensors because ensuring consistent and

detectable force detection on a pressure sensor would require additional structure at the fingertips. To

add support and achieve consistent behaviour, the conductive rubber cords are stabilized and centered

near the tip of each digit with a loop of thread. As the user resists the hand position imposed by the

prototype’s form depiction system, he or she stretches the conductive rubber cord, altering its length,

and consequently the electrical potential read by the analog pins of the Arduino.

To take advantage of the stretch sensors, Arduino’s sketch globally declares a constant that

determines the analog pin where the signal is read, and an integer variable that stores the signal read

from the stretch sensor. An example declaration for the ring finger’s stretch sensors is:

const unsigned int STR_3_PIN = 8;

int strRin;

To read the data from each stretch sensor, the Arduino calls the following function within its update

loop:

void readStretch() {

strThu = analogRead(STR_0_PIN);

strInd = analogRead(STR_1_PIN);

…

}

Lastly, the data from the stretch sensors is added to the information packet that is passed to the host

device over serial connection.

### Overview of Other Implementations

The VRgluv uses pressure sensors to reflect grip strength to the host device. None of the other

prototypes I reviewed used had sensors dedicated to force detection. However, it must be noted that

some early telemanipulation systems discern force based on the difference between the positions of the

master manipulators and the slave actuators. It is possible for existing systems with force feedback to

take a similar approach, calculating the force applied by the user based on the error between the

existing hand conformation and the one imposed by the force feedback system.

### Discussion

The signal yielded by the prototype’s stretch sensors is obstructed by the noise fluctuations. A

more consistent signal may be achieved by using a small-value, non-polar capacitor in parallel with the

sensor, an approach suggested by Nisar et al. for improving the signal from flex sensors (2014). Kalman

filtering may also help mitigate this issue. Variance of the sensor’s movement through its support

structures further detract from signal consistency. The later can be remedied with the use of a thimble

to attach the sensor to the tip of the finger and a channel for the cable to pass though. Using cables

made of different, and as per the demands dictated by the needs of the force depiction system, more

rigid material is also an option worth exploring.

An alternative approach is substituting the existing connective assembly with a more rigid,

strictly structural coupling between the tip of the finger and the servo, implementing a structural

thimble at the tip of the finger, and using a pressure sensor to asses the force that arises between the

fingertip and the thimble. This solution has a dual benefit of enhancing the structural rigidity of the force

depiction system, and delivering a reliable assessment of the force applied by the user’s hand.

## Serial Connection to Host

Now that all of the sensors are ready to be read, and all of the motors are ready to receive

signals, a system must be implemented to take full advantage of the glove-shaped peripheral. In this implementation, the prototype is used to interact with VR environment designed in Unity3D. To

facilitate two-way communication, the Arduino and the relevant script in Unity3D communicate through

a common USB serial port on the host computer. The details of this communication are described

below.

### The Arduino Serial Interface

Starting a Serial Link
The default Arduino libraries supply the methods necessary handle serial communication.

Before starting a serial link, the prototype’s Arduino sketch declares the baud rate, and strings to hold

the input and output values:

const unsigned int BAUD_RATE = 9600;

String output;

String input;

The setup function then changes the timeout to 25 ms, an operation necessary as the default timeout

value for a serial connection is 1000 ms, which noticeably delays the Arduino’s operation when a host

does not have a data packet ready, often giving rise to timeout exception errors. Then, the setup

function begins the serial connection using the predetermined baud rate:

Serial.setTimeout(25);

Serial.begin(BAUD_RATE);

Data Packaging and Exchange
The prototype’s serial connection packages the data to be exchanged between the host device

and the Arduino in strings. The following function, called during the Arduino’s update loop,

concatenates the signal from each flex sensor and stretch sensor to a single string, separated by

commas:

void generateGloveData(){

output = "";

output = output + flxThu;

output = output + ',';

…

output = output + strRin;

output = output + ',';

output = output + strPin;

}

The resulting string is then sent to the host by calling:

Serial.println(output);

The string received from the host that dictates the positions of the servo and vibration motors is

delivered in a similar format. To read and unpackage it, the Arduino uses the following function called in

its loop function:

void readServoData(){

if (Serial.available()){

input = Serial.readString();

int commaPosition;

String readNumberStorage;

int count = 0;

do

{

commaPosition = input.indexOf(',');

readNumberStorage = input.substring(0, commaPosition);

input = input.substring(commaPosition + 1, input.length());

switch(count)

{

case 0:

sersThu = atoi(readNumberStorage.c_str());

break;

case 1:

sersInd = atoi(readNumberStorage.c_str());

break;

…

case 5:

vibrate = atoi(readNumberStorage.c_str());

break;

}

count++;

} while (commaPosition >= 0);

}

}

### Unity3D Serial communication

Establishing a Connection
Before a serial connection can be established in Unity3D, it is necessary to change the “Api

Compatibility Level*” option in PlayerSettings to “.NET 4.x”. After this, the script responsible for

handling the serial connection must include the library:

using System.IO.Ports;

Lastly, the script must declare a SerialPort IO stream:

const string PORT = "COM3";

const int BAUD_RATE = 9600;

SerialPort stream = new SerialPort(PORT, BAUD_RATE);

While the port name is retained between Arduino sessions with the same host, it can be changed

between hosts; when this happens, the correct port name can be found in the Device Manager after

connecting the Arduino.

In the Start() function, the script starts the serial connection and opens the IO stream:

stream.ReadTimeout = 10 000;

stream.Open();

A timeout time of 10 000 ms helps avoid timeout exception errors and is permissible because, as

explained in the next subsection, the serial communication occurs in a separate thread.

In the Update() loop, a function that performs data exchange with he Arduino is assigned to the thread:

serialComThread = new Thread(talkToAdruino);

Multithreading for Serial Communication
For most operations, Unity3D uses a single thread of operations. Serial communication with an

Arduino cannot achieve a rate that reaches the framerates of 60-90 frames per second desirable for VR

experiences. As a result, exchanging data with the Arduino in Unity3D’s main thread can cause unusable framerates below 1 frame per second. One approach to solving this issue is using a separate thread to

handle exchange of data over the serial port in parallel with the main thread. To achieve this, the script

responsible for exchanging data with the Arduino includes the library:

using System.Threading;

Then, the script globally declares the global variable of the Thread type and a Boolean variable to serve

as a flag that an instance of the thread is running.

private Thread serialComThread;

private bool threadRunning;

A Boolean flag is set to true in the beginning of the method performed by the thread and set to false

once the function’s operation is complete. It is used to ensure that new instances of the thread are

started before an existing instance is complete, a scenario which can overload the processing capacity of

the host hardware by opening an excessive number of parallel threads, leading to a forced closure of the

Unity3D editor:

if(!threadRunning)

serialComThread.Start();

Additionally, the script encapsulates any operations that access the same variables as the thread in

if(!threadRunning) {…}

This practice prevents race conditions between parallel threads. Race conditions can, for example, be

problematic if the thread tasked with exchanging information with the Arduino sends a string data

packet before it is concatenated to include all information, thus sending an incomplete set of data to the

Arduino.

The method invoked in the serial communication thread is as follows:

private void talkToAdruino()

{

threadRunning = true;

serialInput = stream.ReadLine();

stream.WriteLine(serialOutput);

threadRunning = false;

}

While inspired for use in the project to mitigate delays in serial communication, threading is

commonly used to perform time-consuming calculations with a lesser impact on the program’s

performance. For instance, the prototype’s script can further be optimized by using a secondary thread

to process data packages, and map values.

Data Packaging
Consistent with the format in the Arduino’s sketch, the script responsible for glove behaviour in

Unity3D exchanges data packets in the form of strings. While differences between the methods for

handling strings found in Unity3D and Arduino IDE necessitate different syntax, similar techniques are

used to disassemble and concatenate information packets. The string that stores serial input,

serialInput, is read in the following manner:

int commaPosition;

do

{

commaPosition = serialInput.IndexOf(',');

string readNumberStorage = serialInput.Substring(0, commaPosition);

serialInput = serialInput.Substring(commaPosition + 1);

switch (count)

{

case 0:

flxThu = int.Parse(readNumberStorage);

break;

case 9:

strPin = int.Parse(readNumberStorage);

break;

}

count++;

} while (commaPosition >= 0);

The string that stores serial output, serialOutput, is concatenated using:

serialOutput = "";

serialOutput = serialOutput + serThu;

serialOutput = serialOutput + ',';

…

if (vibrateOn)

serialOutput = serialOutput + 1;

else

serialOutput = serialOutput + 0;

Hand Model Manipulation
The script responsible for handling glove behaviour applies the data to a hand model supplied

by the SteamVR asset. After disabling the animator and SteamVR behavioural scripts, it is possible to

take advantage of the hand model’s skinned mesh renderer and representation of pivotal points of the

hand as empty child game objects to shape the hand model’s conformation. To facilitate spatial tracking,

the hand model is imported as a child to the right hand anchor of the VR camera rig system in use. The script, placed under the hand model’s parent object, takes reference to the Transform parameters of

the pivotal game objects representative of digit joints, and locally rotates them around the Z axis based

on data read from flex sensors. For instance, the thumb’s rotation is manipulated by rotating the objects

that represent the game objects that represent its metacarpophalangeal and interphalangeal joints:

flxThu = Map(flxThu, 250, 90, 0, -90);

jntThu1.localRotation = Quaternion.Euler(0, 0, flxThu);

jntThu2.localRotation = Quaternion.Euler(0, 0, flxThu);

Before a rotation position can be set, the flex sensor data is mapped using a function adapted from the

Arduino IDE library in a manner that a range of 250 to 90 is rescaled to a range of 0 to -90, realistically

representing the curvature of a digit in each joint. The values used can be altered to calibrate the

relative flexion of each join on the hand model. The script targets the quaternion localRotation to

achieve this task because it allows setting the rotation of a game object relative to its parent.

Conversely, the quaternion rotation sets the rotation of the game object relative to the world space,

while the method Rotate(float xAngle, float yAngle, float zAngle, Space relativeTo =

Space.Self) applies a rotation to the object every time it is invoked rather than setting it to the desired

value; while both alternative options can be used reach the desired effect, they would unnecessarily

additional code to implement. The Euler(float x, float y, float z) method in the Quaternion

class trivializes the setting of rotation to developers who prefer to use Euler angles rather than

quaternions by converting rotation parameters to the later format.

Application within VR Experience
Reading the states of sensors and setting the states of motors through the script that handles

glove behaviour gives prospective developers numerous possibilities for interactions in VR. To

demonstrate the application of the prototype I implemented a rudimentary object grabbing system. A

contact of a collider on the hand model with a virtual object triggers the retraction of user’s digits using

servo motors to give the haptic sensation of wrapping his or her hand around an object. The system can

be altered to set the servos to different positions depending on the form of the object. A more elaborate

system can also be developed to trigger the retractive action of servomotors when colliders on inner

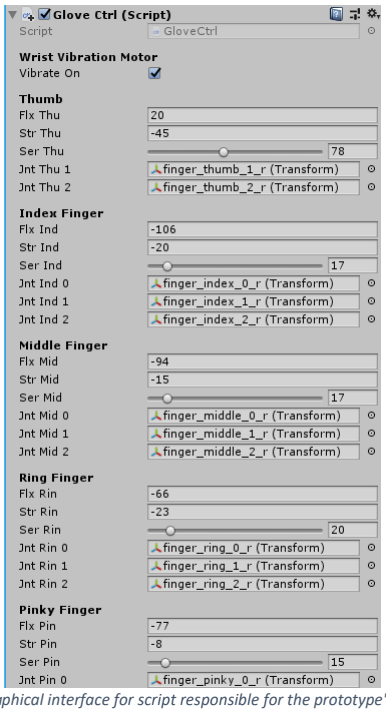
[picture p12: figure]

surfaces of individual digits come in contact with virtual surfaces. Once the conformation of the user’s

hand is constrained to reflect the grabbable object, the stretch sensor signals are monitored to asses

Figure 4 Graphical interface for script responsible for the prototype's behaviour.

whether the user is applying sufficient force to grab the object. Once the threshold of force is reached,

the object is picked up by becoming the child of the hand model object and the user is informed of his or

her success with the engagement of the vibration motor. A drop of the stretch sensor signal below the

threshold needed to pick up the object prompts the release of the object and a disengagement of the

vibration motor. When the stretch sensor signal is not sufficiently stable to accurately reflect the force

applied by the user, as was the case in the testing of the prototype, finger curvature read from flex

sensors can be read instead. Once the object’s collider ceases to interact with the hand model’s collider,

the servo motors are adjusted to the position least restrictive on hand operation.

## Applications of Technology

The technology found in the prototype has uses far beyond VR entertainment. While tracking

and representing the behaviour of digits serves as a foundation for any VR implementation of a glove-

shaped peripheral, it also has applications on its own; with he help of gesture recognition, hand tracking

can facilitate unique communication systems and new opportunities to learn new skills such as sign

language (Weissmann & Salomon, 1999). The addition of haptic feedback widely expands possibilities in

diverse industries. Accurate representation of virtual objects’ shapes can improve user’s performance in

learning about abstract concepts such as force fields and molecule docking, computer assisted design,

robot-assisted surgery, and telepresence scenarios (Brooks et al., 1990; Burdea, 1993; Okamura, 2009).

Force detection, although seldom implemented with discrete sensors, can enhance existing

implementations of force-feedback systems. Connelly et al. (2010) designed a rehabilitative glove that is

capable of hand tracking and uses a pneumatic system to assist stroke patients in finger extension, an

operation that the group often finds challenging. Allin, Matsuoka, & Klatzky (2002) use a desktop force

measurement system to evaluate self-imposed limits on force production, which are hypothesized

different among stroke victims. By enhancing the rehabilitative glove with a precise force detection

system, the assistive force exerted by the glove can be gauged more accurately, and the force applied by the patients can serve as a valuable parameter for rehabilitation progress. Research reviewed Okamura

(2009) demonstrates that force detection and representation can improve the performance and safety

of robot-assisted surgery. While the prototype I describe is far from the level of refinement that would

make it beneficial in most of these scenarios as is, continued development and intertwining with existing

designs can yield a series of products with potential in the fields of education, medicine, engineering,

and design.

## Conclusion

Manual interaction is a core part of modern VR experiences. A peripheral with accurate digit

tracking, haptic feedback, and force detection would be an important step to maximizing the

believability and impressiveness of a VR system. In this project, a working prototype of such a peripheral

was built and tested. Some problems remain including but not limited to a lack of tracking of the

position of metacarpophalangeal joints, a lack of rigidity in the haptic feedback system, and an unusably

low signal to noise ration of stretch sensor. Nonetheless, the prototype acts as a proof-of-concept for a

glove-shaped peripheral for VR.

## References

Allin, S., Matsuoka, Y., & Klatzky, R. (2002). Measuring just noticeable differences for haptic force

feedback: implications for rehabilitation. In Proceedings 10th Symposium on Haptic Interfaces for

Virtual Environment and Teleoperator Systems. HAPTICS 2002 (pp. 299-302). IEEE.

Brooks Jr, F. P., Ouh-Young, M., Batter, J. J., & Jerome Kilpatrick, P. (1990, September). Project

GROPEHaptic displays for scientific visualization. In ACM SIGGraph computer graphics (Vol. 24,

No. 4, pp. 177-185). ACM.

G. Burdea, Virtual Reality Systems and Applications,” Electro’ 93 International Conference, Short

Course, Edison NJ, April 1993.

Burdea, G. C. (2000). Haptics issues in virtual environments. In Proceedings Computer Graphics

International 2000 (pp. 295-302). IEEE.

Connelly, L., Jia, Y., Toro, M. L., Stoykov, M. E., Kenyon, R. V., & Kamper, D. G. (2010). A pneumatic

glove and immersive virtual reality environment for hand rehabilitative training after stroke. IEEE

Transactions on Neural Systems and Rehabilitation Engineering, 18(5), 551-559.

Nisar, O. (2014, May). Performance Optimization of a Flex Sensor Based Glove for Hand Gestures

Recognition and Translation, International Journal of Engineering Research & Technology, Vol. 3,

Issue 5. Faisal Town, Lahore, Pakistan.

Novatel. (n.d.). IMU Errors and Their Effects. Retrieved April 11, 2019, from

https://www.novatel.com/assets/Documents/Bulletins/APN064.pdf.

Okamura, A. M. (2009). Haptic feedback in robot-assisted minimally invasive surgery. Current opinion in

urology, 19(1), 102.

Pollack, A. (1989, April 10). For Artificial Reality, Wear A Computer. Retrieved from

https://www.nytimes.com/1989/04/10/business/for-artificial-reality-wear-a-computer.html

Rosson, L. (2014, April 15). The Virtual Interface Environment Workstation (VIEW), 1990. Retrieved from

https://www.nasa.gov/ames/spinoff/new_continent_of_ideas/

Stone, R. J. (2000, August). Haptic feedback: A brief history from telepresence to virtual reality.

In International Workshop on Haptic Human-Computer Interaction (pp. 1-16). Springer, Berlin,

Heidelberg.

Sturman, D. J., & Zeltzer, D. (1994). A survey of glove-based input. IEEE Computer graphics and

Applications, 14(1), 30-39.

Sutherland, I. E. (1965). The ultimate display. Multimedia: From Wagner to virtual reality, 506-508.

Weissmann, J., & Salomon, R. (1999). Gesture recognition for virtual reality applications using data

gloves and neural networks. In IJCNN'99. International Joint Conference on Neural Networks.

Proceedings (Cat. No. 99CH36339) (Vol. 3, pp. 2043-2046). IEEE.

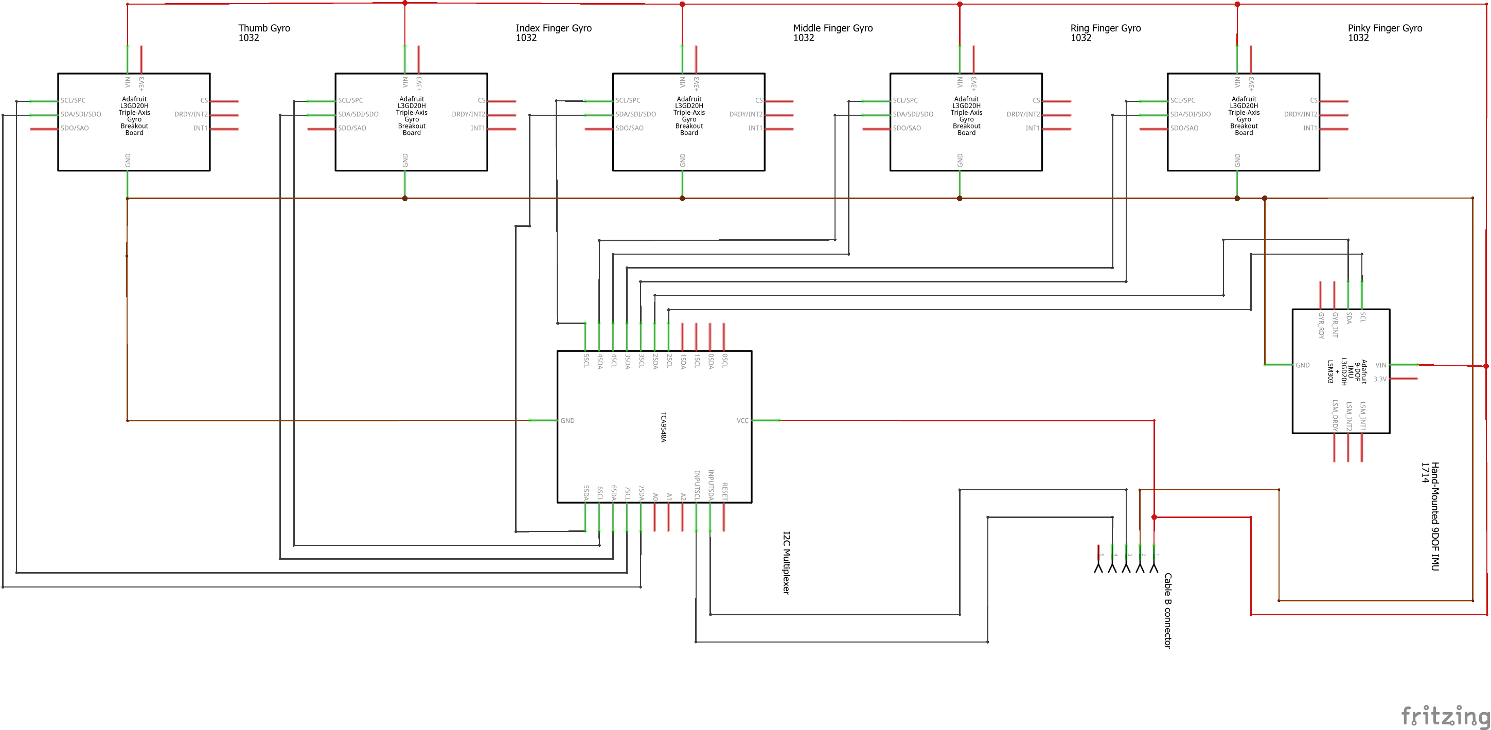
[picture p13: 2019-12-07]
hardware/Gyro Manipulation Board_schem.png

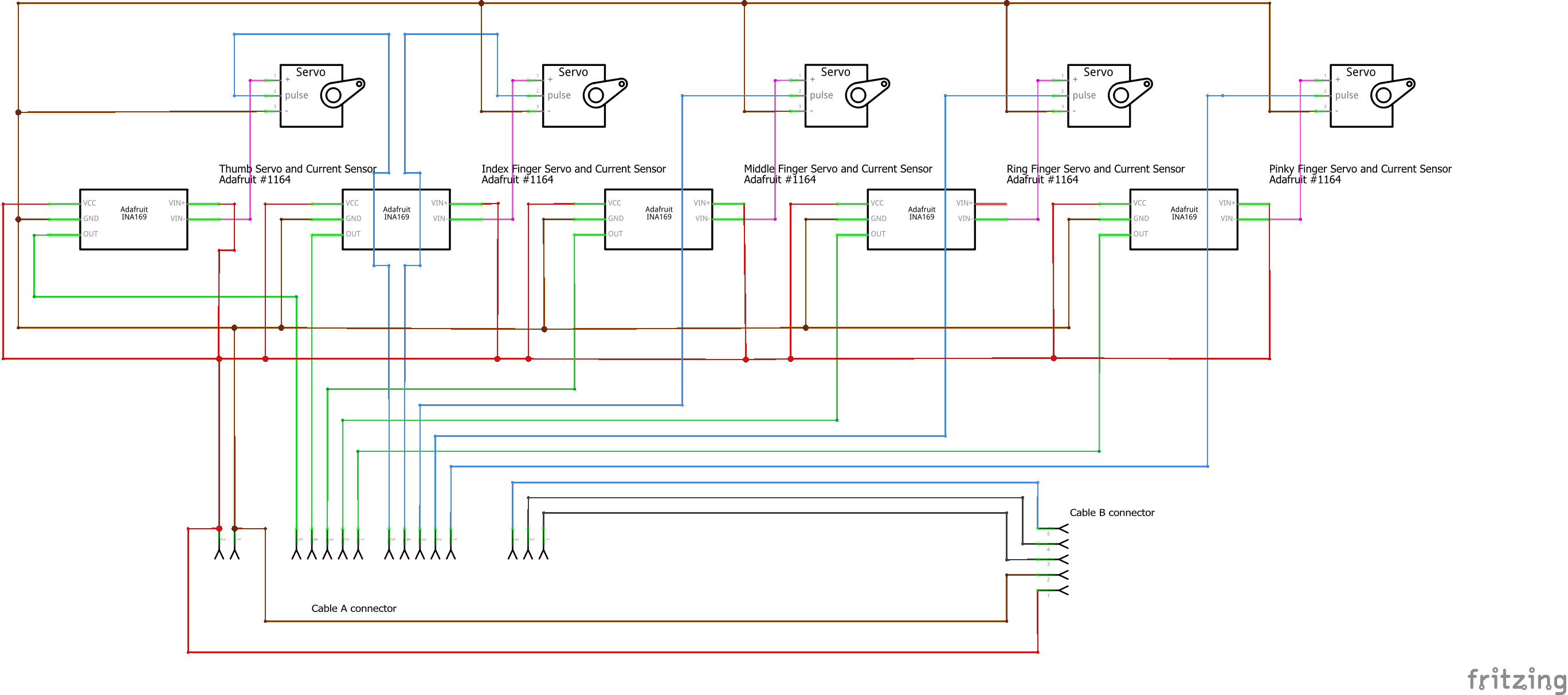
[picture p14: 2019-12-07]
hardware/Servo Manipulation Board_schem.png

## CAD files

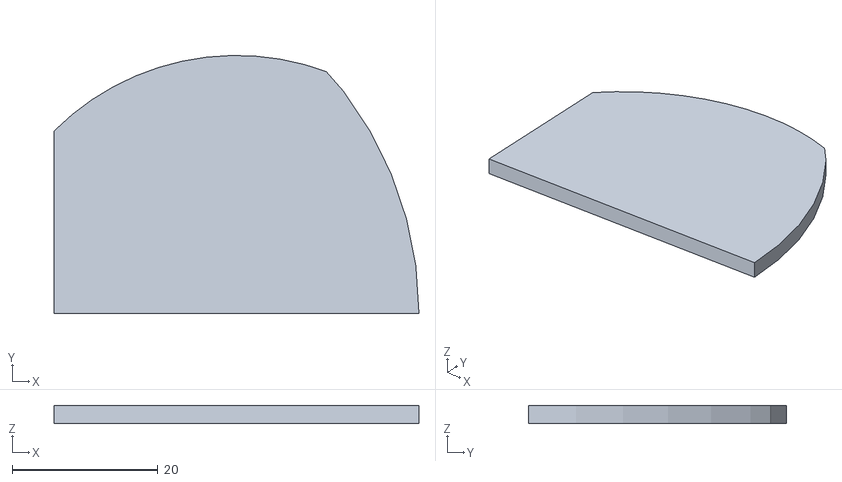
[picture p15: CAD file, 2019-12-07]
hardware/Servo Lobe Side.stl
50.0 x 35.3 x 2.50

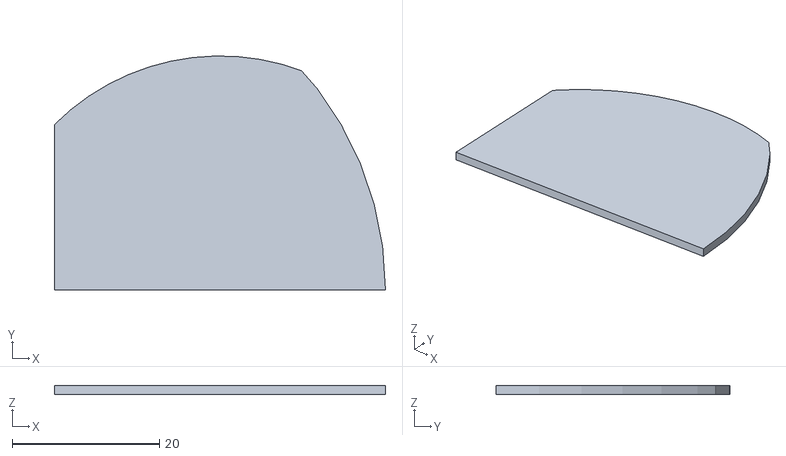
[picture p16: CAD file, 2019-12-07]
hardware/Servo Lobe Middle.stl
45.0 x 31.8 x 1.25

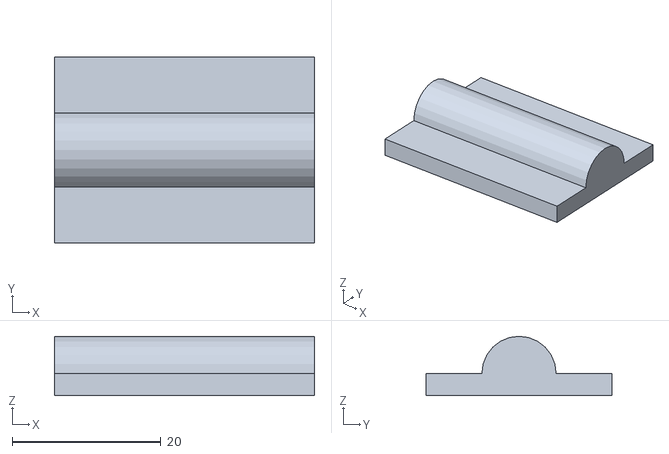
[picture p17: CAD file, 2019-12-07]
hardware/Digit Plate Lid.stl
35.0 x 25.0 x 8.00

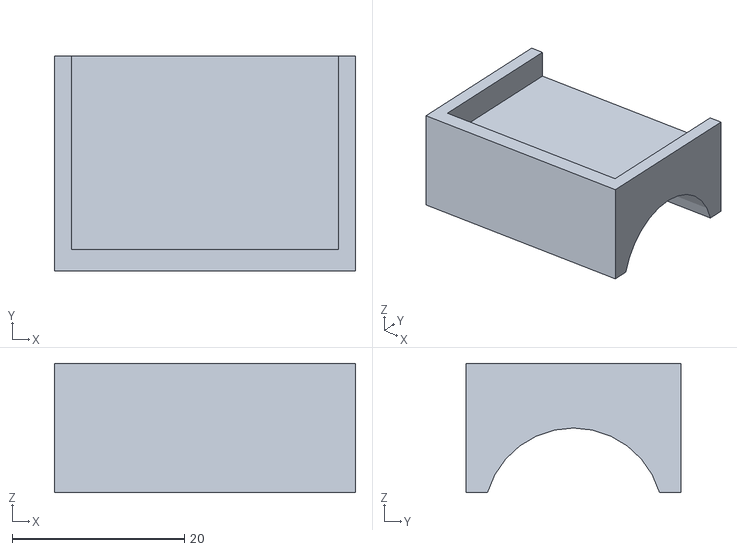
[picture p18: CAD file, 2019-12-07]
hardware/Digit Plate Base.stl
35.0 x 25.0 x 15.0

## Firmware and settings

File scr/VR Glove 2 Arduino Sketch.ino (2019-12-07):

/*
 * ~~~~~~~~~~VR Glove 2 Arduino Sketch~~~~~~~~~~
 *  0.0.9
 * 
 * This program handles the input and output required 
 * for the VR glove.
 *
 *  ***THIS CODE IS A WORK IN PROGRESS***
 * To-do list:
 *  - change the nomenclature of the vibration motor pin to be more generic  
 *
 * New in this version:
 *  - fixed intermittent stalling durin gyro initialization
 * 
 * The code is designed to work with a project-specific 
 * shield to be placed on an Arduino MEGA. 
 * More details coming in a future update.
 * 
 * Latest update: December 7, 2019
 * 
 * Zakhar Kanyuka - CS 207 
 * VR Glove Project
 *
 * 
 */


#include<Servo.h>
#include <Wire.h>
#include <Adafruit_Sensor.h>
#include <Adafruit_L3GD20_U.h>

// general global varible declarations
const int BAUD = 9600; // baud rate for serial communication
const int LOOP_DELAY = 50; // delay between loop iterations
  // set to 500 ms for debugging purposes

// servo declarations
Servo servos[5]; // thumb to pinky
const int servo_pins[] = {6, 5, 4, 3, 2}; // thumb to pinky

// vibration motor declarations
const int vib_pin = 7;
bool vib_state;

// current sensor declarations
const int isensor_pins[] = {A0, A1, A2, A3, A4}; // thumb to pinky  

// gyroscope object declaration
Adafruit_L3GD20_Unified gyro[6];
const int gyro_addr[] = {2, 3, 4, 5, 6, 7}; // correspond to the addresses on the MUX

void setup() 
{
  // serial communication start
  Serial.begin(BAUD);

  Serial.println("Setup initialized.");
  
  // servo attachment
  for(int i = 0; i < 5; i++)
  {
    servos[i].attach(servo_pins[i]);
  }

  ////////////////////////////////////////////////////////
  // A block of code adapted from an I2C scanner by 
  // gist.github.com/riyas-org
  //
  // The piece of code appears to relieve stalling issues 
  // likely caused by the I2C mux
  ////////////////////////////////////////////////////////
  byte error, address;
  int nDevices;

  for(int MUX_address = 0; MUX_address < 8; MUX_address++)
  {

    MUXSelect(MUX_address);
    nDevices = 0;
    for(address = 1; address < 127; address++ ) 
    {
    // The i2c_scanner uses the return value of
    // the Write.endTransmisstion to see if
    // a device did acknowledge to the address.
    Wire.beginTransmission(address);
    error = Wire.endTransmission();
   
    } 
    delay(50);           // wait before next scan
  }
  ////////////////////////////////////////////////////////

  // gyro initialization
  for(int i = 0; i < 6; i++)
  {
    MUXSelect(gyro_addr[i]);
    gyro[i] = Adafruit_L3GD20_Unified(20);
    gyro[i].enableAutoRange(true);
    //Serial.println("before begin");
    gyro[i].begin(); // This line was the culprit of the 
					 //intermittent stalling that 
					 // necessitates the above excerpt 
					 // from the I2C scanner
    //Serial.println("after begin");
  }

  
  Serial.println("Setup complete.");  
}

void loop()
{
  int servo_positions[5]; // holds desired servo positions
  readHostInstruction(servo_positions);
  positionServos(servos, servo_positions);
  applyVibState(vib_state);
  
  int isensor_data[5]; // holds current (I) sensor data
  readCurrent(isensor_data);
  
  int gyro_data[6][3]; // holds gyro data
  readGyros(gyro_data);
  
  writeToHost(buildOutputToHost(isensor_data, gyro_data)); 
  
}

// Reads instructions from host, processes them, and stores them in appropriate containers
// (just handles servo positions for now)
//
// input format: s#0#,#1#,#2#,#3#,#4#,...e
void readHostInstruction(int servo_positions[])
{
  
  if(!Serial.available()) // ensures that serial data available
    return;
  
  String hostInput = Serial.readString();
  
  if(!((hostInput.charAt(0) == 's') && (hostInput.charAt(hostInput.length()-1) == 'e')))
    // ensures data received is a complete string in the appropriate format
    // if not, returns from the function
  return;
  
  int count = 0;
  
  do
  {
    int commaPosition = hostInput.indexOf(',');
    String numString = hostInput.substring(1, commaPosition);
    hostInput = hostInput.substring(commaPosition, hostInput.length());
    
  if(count <= 4)
    servo_positions[count] = atoi(numString.c_str());
  else
    vib_state = atoi(numString.c_str());
    
    count ++;
  } while (count < 6);
}

// Reads current and stores data in the parameter array
void readCurrent(int isensor_data[])
{
  for(int i = 0; i < 5; i++)
  {
    isensor_data[i] = analogRead(isensor_pins[i]);
  }
}

// Reads gyros and stores data in the parameter array
void readGyros(int gyro_data[][3])
{
  // This function will be completed once the setback surrounding the I2C hardware is resolved.
  // For now it mirrors the single gyro signal to all gyros in the array
  sensors_event_t event; 

  for(int i = 0; i < 6; i++)
  {
      MUXSelect(gyro_addr[i]);
      
      gyro[i].getEvent(&event);
      
      gyro_data[i][0] = event.gyro.x * 100;
      gyro_data[i][1] = event.gyro.y * 100;
      gyro_data[i][2] = event.gyro.z * 100; 
    

    
  }
  
  
}

// Writes positions to servos
void positionServos(Servo servos[], int servo_positions[])
{
  for(int i = 0; i < 5; i++)
  {
    servos[i].write(servo_positions[i]);
  }
}

// Writes state to vibration motor
void applyVibState(bool vib_state)
{
  digitalWrite(vib_pin, vib_state);
}

// Builds output string 
// output format: s#0#,#1#,#2#,#3#,#4#,e
String buildOutputToHost(int isensor_data[], int gyro_data[][3])
{
  String outputToHost = "";
  
  outputToHost = outputToHost + 's';
  
  for(int i = 0; i < 5; i++)
  {
    outputToHost = outputToHost + isensor_data[i];
    outputToHost = outputToHost + ',';
  }

  for(int i = 0; i < 6; i++)
  {
    outputToHost = outputToHost + gyro_data[i][0];
    outputToHost = outputToHost + ',';
    outputToHost = outputToHost + gyro_data[i][1];
    outputToHost = outputToHost + ',';
    outputToHost = outputToHost + gyro_data[i][2];
    outputToHost = outputToHost + ',';
    
  }
  
  // further concatenation can be added here
  
  outputToHost = outputToHost + 'e';

  return outputToHost;
}

// Delivers string to host over serial
void writeToHost(String outputToHost)
{
  Serial.println(outputToHost);
}

// Selects address for I2C MUX
// This function and other MUX manipulation highly inspired by:
// https://learn.adafruit.com/adafruit-tca9548a-1-to-8-i2c-multiplexer-breakout/wiring-and-test
#define TCAADDR 0x70
void MUXSelect(uint8_t i)
{
  if(i > 7) return;
  
  Wire.beginTransmission(TCAADDR);
  Wire.write(1 << i);
  Wire.endTransmission();
}

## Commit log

2019-12-07 Create VR Glove 2 Arduino Sketch.ino
    This is the project submission milestone version of the sketch.
    Former iterations were committed to a different repository.
2019-12-07 Add files via upload
    Please see the local read-me file for descriptions of the files and their use (or the lack thereof in the project).
    [Digit Plate Base.stl, Digit Plate Lid.stl, Servo Lobe Middle.stl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]
2019-12-07 Add files via upload
    Libraries for simple handling of Adafruit gyroscope breakout boards and other Adafruit Sensors.
2019-12-07 Update hardware_readme.text
    Added information about the included schematics.
2019-12-07 Add files via upload
    These are the schematics for the three electronic component boards of the prototype.
2019-12-21 Updated Project Write-Up
    Appendices were updated to include an image of the completed prototype and the URL of this repository.
